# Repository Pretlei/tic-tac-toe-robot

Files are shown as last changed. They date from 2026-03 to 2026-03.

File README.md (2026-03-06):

# tic-tac-toe-robot
An autonomous Tic Tac Toe robot you can play against! Huge thanks to Maxim Beauchemin, Chris Dietcher, and Andrew Jang for their shared commitment and hard work that made this project possible.

## Project Overview:
An autonomous Tic Tac Toe Robot built using VEX IQ and Tetrix components, as well as 3D printed parts and an aluminum extrusion. Uses a 3-axis motor system with color and distance sensors to interact with the X's and O's. Programmed game logic and robot instructions using C++ and VEX IQ Code. 



Read the Final Report for in-depth documentation and code!

## Links to Demo Videos
Pick and Place Demonstration: https://drive.google.com/file/d/1chxBTSAvIlYaxoZVmUNdCmPReI9nGJBg/view?usp=sharing

Scan and Play Demonstration: https://drive.google.com/file/d/1ZsqPEp68fcEzI5YiyI5k1Ya-KQUuAkkN/view?usp=sharing

## Issues with the Tic Tac Toe Robot:
- Motor inaccuracy
- Sensor inaccuracy
- Overheating of VEX IQ motors
- Slight lack of proper building components, and therefore, structural integrity

Unfortunately, time and resources were severe constraints in this project. We made the best of what we had! It was an excellent learning experience.

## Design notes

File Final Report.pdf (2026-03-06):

# The Tic-Tac-Toe Robot

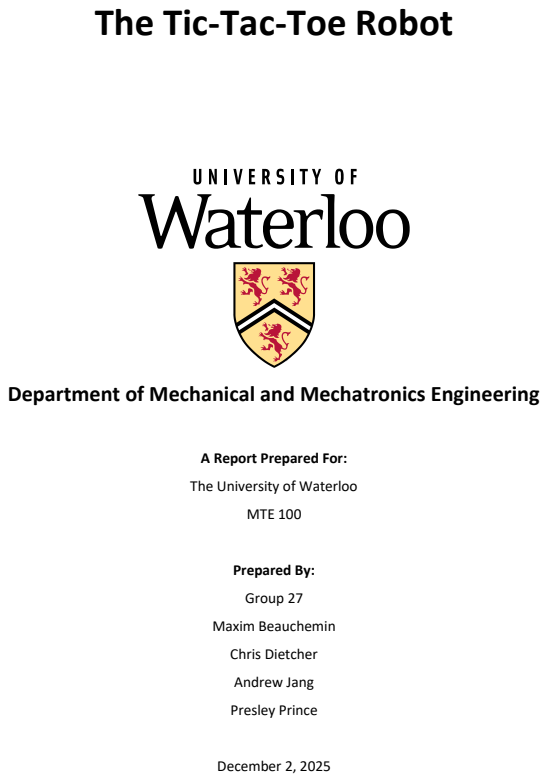
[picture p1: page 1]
MTE 100; Prepared By:; Group 27; Maxim Beauchemin; Chris Dietcher; Andrew Jang; Presley Prince; December 2, 2025

Department of Mechanical and Mechatronics Engineering

A Report Prepared For:
The University of Waterloo

i

December 2, 2025

MTE 100 and MTE 121 Teaching Teams

Department of Mechanical and Mechatronics Engineering

University of Waterloo

200 University Ave W.

Waterloo, Ontario, N2L 3G1

Dear Teaching Teams,

As a team, we would like to express our deepest gratitude to the entire teaching team. Without

you we would not have come up with this project which, while having had several very late nights and a

few clawed-out hairs, we are incredibly proud to have created.

Instruction from all our professors was essential to learn the theory to build this robot. From

Professor Bedi’s fun lectures of components and the design cycle to Abdullah’s EGAD labs, and Professor

Mostafa’s programming PowerPoints. The project design, 3D-printed parts, and C++ programming

would have all been impossible without their foundational teaching. Ryan Consell’s advice proceeding

the formal presentation was key in many parts of our design.

Additionally, the MTE 100 tutors were key in the project execution. Their continuous feedback

throughout the project and near-constant availability made many of our largest issues into just a quick

visit to their office.

Lastly, we would like to thank the amazing co-op students at WatIMake who taught us the

basics of 3D printing.

This report was written entirely by Group 27. Apart from acknowledgements listed above and

references, the program and robot were created entirely by Group 27 as well.

Best Regards,

Maxim Beauchemin

Chris Dietcher

Andrew Jang

Presley Prince

ii

## Table of Contents

iii

5.3 The Functions | 18
5.4 Data Storage | 22
5.5 Decisions and Trade-offs | 23
5.6 Testing Procedures | 24
5.7 Significant Problems | 25
6.0 Verification | 26
6.1 Fulfilled Constraints | 26
6.2 Failed Constraints | 26
7.0 Project Plan | 28
7.1 Tasks Splitting | 29
7.2 Revisions to Project Plan | 29
7.3 Project Plan vs Actual Timing | 30
8.0 Conclusions | 31
8.1 Successes | 31
8.2 Failures | 31
9.0 Recommendations | 32
9.1 Mechanical Recommendations | 32
9.2 Software Recommendations | 33
References | 34
Appendix A – C++ Code | 1

iv

## List of Figures

Figure 27. A description of the project plan after the formal presentation. Taken from the formal

v

## List of Tables

Table 1. A table of all X and Y positions for the motors for each square of the board. The position is given

in degrees and obtained from motor encoders through testing. The array indices are visualized in Figure

26 | 24

Table 2. A table of distance sensor readings corresponding to the number of pieces left in the stack. The

values assume that all pieces are left in the stack or on the board. The values were obtained through

distance sensor reading and refined in testing | 25

vi

## Summary

The MTE100 robot project for Chris, Maxim, Andrew and Presley was an autonomous tic-tac-toe

robot. This robot was designed to solve the problem of one of the team members being too busy at

university to play his cousin in tic-tac-toe.

The project started following the design cycle and discussing the constraints and criteria for robot

design. After need synthesis was complete through analysis of criteria and constraints, preliminary

designs were drafted for the robot’s function. Designs for given parts were selected and then

manufactured into a functional robot. There were many iterations of redesign adjusting both small and

large details about the robot’s design. Next, the robot was programed to play a game of tic-tac-toe,

using a color sensor to scan the board and a three-axis motor system with a claw to move pieces.

Various methods of verification were used to test the robot’s functionality and adjust

preprogramed encoder values. During the validation phase of the design cycle problems started to arise

in the robot’s functionality. Namely, the Z-axis motor was too weak to carry the load of the claw its full

vertical distance and encoders inaccuracies made piece pick up difficult for the robot. However, in the

final demo the robot was able to perform tic-tac-toe moves from various starting positions but could not

play a full game due to the previously described errors.

It is concluded, for future designs of a tic-tac-toe robot to redesign the Z-axis motor with

potentially a gearing system to reduce torque, use lead screws to increase motor encoder accuracy, and

consider using the Minimax algorithm to further optimize the robot’s gameplay.

## 1.0 Introduction

The MTE100 project is a first-year design project in which students find a problem and design a

robotics solution to solve the problem. The criteria for this project were that it must solve a problem,

use at least 3 motors and 4 inputs, and contain at least six functions in the robot’s code. This design

project report will focus on the development of an autonomous tic-tac-toe robot.

This MTE100 robot project was designed to solve the problem of one of the group members not

being able to beat his cousin at tic-tac-toe. Chris has a long-standing tic-tac-toe rivalry with his 8-year-

old cousin and cannot beat him since he is too busy studying at Waterloo. So, the group devised a plan

to make an autonomous tic-tac-toe robot to beat Chris’s cousin while he is away. The goal for this robot

was to design a simple to use, autonomous tic-tac-toe robot capable of playing full games of tic-tac-toe

with little user assistance.

Tic-tac-toe is a simple game involving players taking turns placing X’s or O’s on a 3x3 grid. The

goal is to get three X’s or O’s in a row to win. The robot is designed to be able to scan any tic-tac-toe

board and play a specific move to bring it closer to winning or tying the game. The robot is also designed

to play against a player having a button to press signifying it is the robot’s turn. This design allows it in

theory to play whole games against another player, itself or from any given valid position.

This robot was developed using Vex IQ electronics and parts, Tetrix parts and various 3d printed

elements. Vex IQ is an intuitive design framework for assembling basic robotics systems using plastic,

snap-together pieces [1]. Additionally, Vex IQ has very inaccurate sensors that were a major source of

troubleshooting for later design iterations of the robot. Tetrix parts were used for main stabilization of

robot design since the aluminum extrusions were more rigid than plastic Vex IQ parts. Lastly, custom

parts were made to fit specific functions of the robot that would be hard to model using Vex IQ or Tetrix

parts. The primary use for 3D printer was for complex parts like the Claw and Board which will be talked

about in further detail in 4.0 Mechanical Design and Implementation.

## 2.0 Scope

### 2.1 Functionality

The robot autonomously played tic-tac-toe by moving physical pieces from a stack onto a board.

The pieces and board are shown in Figure 1. To play, the robot recognized when it was its turn, scanned

the board, and placed a piece on the board.

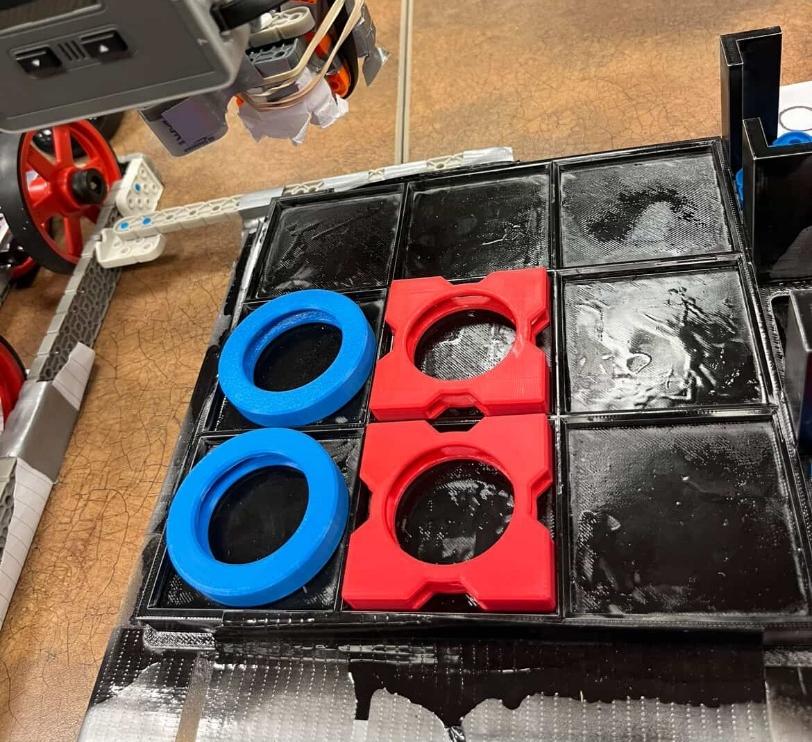
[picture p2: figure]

Figure 1. Tic-tac-toe board and pieces

During regular operation, the robot would wait for the user to make their move and press the

touchLED. The press informed the robot that it was its turn. The robot would then zero itself by moving

to its starting position. This starting position was located at the top-left corner of the board relative to

the user. In this position, the claw assembly was also raised to its highest possible elevation. The starting

position is shown in Figure 2.

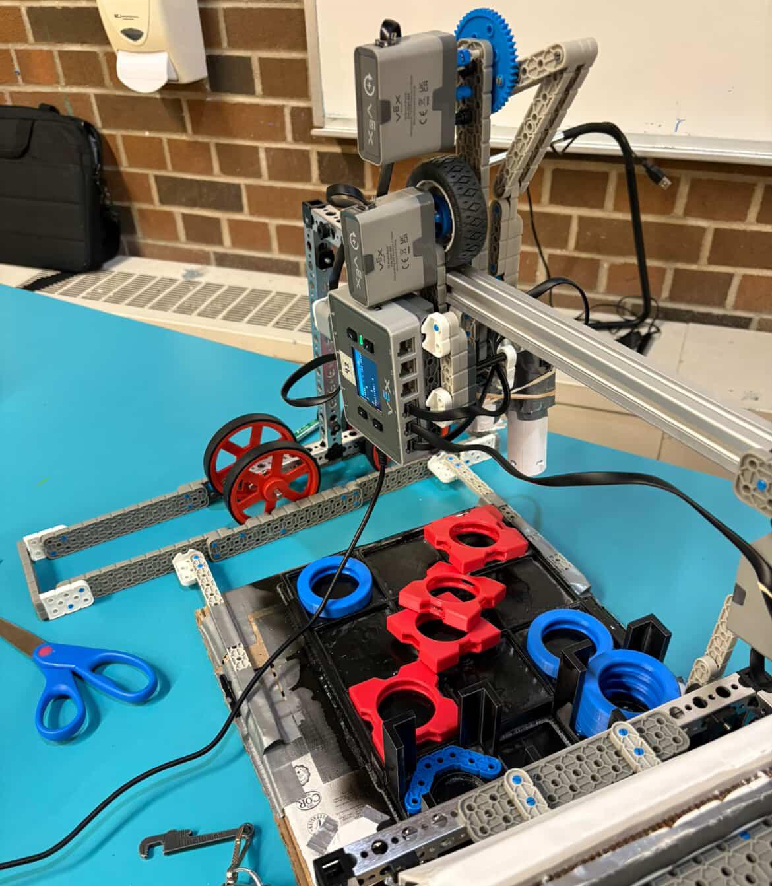
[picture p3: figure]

Figure 2. Starting position of robot

Once the robot reached its starting position, it would then proceed to scan the board. Scanning

the board allowed the robot to determine what pieces have been placed, where said pieces were, and

what piece it should place and where it should place it. Scanning the board also enabled the robot to see

if the game was over, or if any cheating has been done by the user. For this project, cheating was

defined as having an invalid number of pieces on the board. Since X always goes first, the number of X-

pieces must have been one greater or equal to the number of O-pieces on board. To scan the board, the

robot lowered the claw assembly to its scan height and then moved the color sensor (located on the

claw assembly) over each space on the board. The scan height was the lowest height the claw could go

without hitting any pieces placed on the board. This is illustrated in Figure 3. After completing the scan,

the robot returned to its starting position.

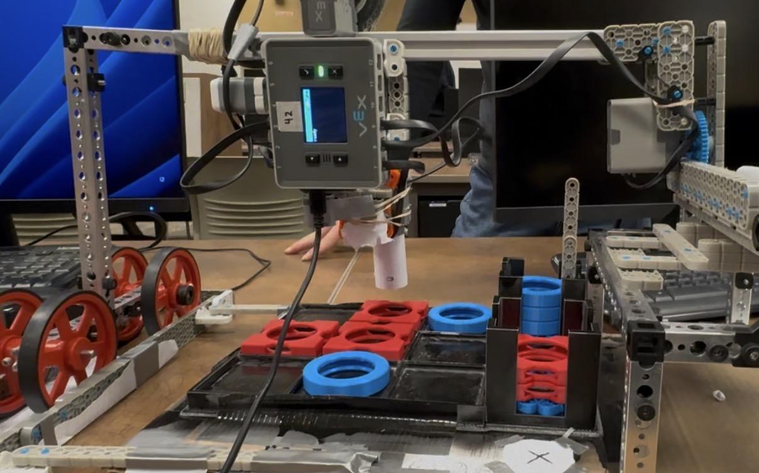
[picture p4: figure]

Figure 3. Robot scanning the board

The robot’s next task was to pick up a piece and place it on the board. This task was only

completed if the game was not over and if cheating was not detected. First, the robot would move to

the correct stack of pieces based on the scan of the board. The claw assembly would then be released

and allowed to fall to its lowest height. The claw would then be raised to the height of the top piece in

the stack. The claw was then extended into the holes of the piece. The claw assembly would then return

to its starting position for placement. After returning to the starting position, the robot moved the claw

assembly to the space it determined would result in the best move. The claw is then lowered and then

retracted, allowing the piece to fall into place on the board.

The robot then returned to the starting position and waited for the user to complete their next

turn.

### 2.2 Measurements and Readings

Throughout the robot’s operation, the robot kept track of its position, differentiating between

the different pieces on the board, and whether it was its turn. The robot also used the inputs to decide

when to end the program. The robot received readings from the touchLED, motor encoders, color

sensor, and distance sensor.

The touchLED acted as a method of communication between the user and the robot. Pressing

the touchLED informed the robot that the user had completed their turn and that it was the robot’s

turn. The touchLED also acted as the shutdown mechanism for the robot. While the robot is waiting for

the user, holding down the touchLED for three seconds or more would have shut down the robot.

The motor encoders were used to keep track of the position of the claw assembly throughout

the entire operation of the robot. This includes the position in the x-axis, y-axis, and z-axis. Keeping track

of the claw’s position was important as the robot had to move to many different locations in three-

dimensional space. These locations included each space on the board, the two stacks of pieces, and each

of the five possible heights in each stack. Only the encoder values of three of the four motors were used

to measure position; the fourth motor did not control the motion of the claw assembly. The motor

encoder values were measured in degrees.

The color sensor was used to differentiate between X-pieces, O-pieces, and empty spaces. The

X-pieces were red, the O-pieces were blue, and the board was black. When scanning space on the board,

the color sensor took 20 measurements and used the lowest hue value. See [Appendix A, line 564] for

more information on the color differentiation process.

The distance sensor was used to keep track of the height of the claw when the robot was picking

up pieces from the stacks. The distance sensor was used in place of the encoder for the z-axis motor

because the distance sensor was believed to be more accurate. Increased accuracy was required when

picking up pieces due to the small size of the pieces.

### 2.3 Interaction with the Environment

Interaction with the environment was accomplished using the robot’s four motors. Three of the

motors were used to control the position of the claw assembly. Each of these motors was responsible

for movement along one of the three main axes. One motor controlled x-axis motion; another motor

controlled y-axis motion; a third motor controlled z-axis motion. The motors and their respective axes

are shown in Figure 4. These three motors allowed the robot to reach each of the nine spaces on the

board, the two stacks, and each of the five heights in both stacks. These motors also allowed the robot

to properly position the color sensor for reading the board. The fourth motor was located on the claw

and controlled its extension and retraction. This motor enabled the robot to pick up and put down

pieces.

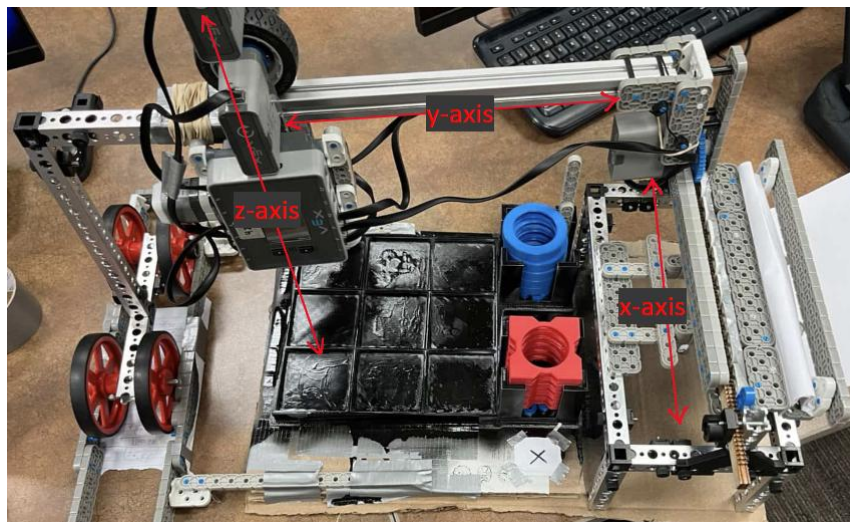
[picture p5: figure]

Figure 4. Motors and their axes

### 2.4 Task Completion

There were four main tasks the robot accomplished during regular operation: waiting for the

user, returning to the starting position, scanning the board, and placing pieces. The robot recognized the

completion of each of these tasks in different ways. Waiting for the user was completed when the

touchLED was pressed. Returning to the starting position was completed by spinning the motors in the

direction of the starting position and setting a timer. This task was completed when the timer reached

the reset time of four seconds for the x-direction and y-direction and three seconds for the z-direction.

Scanning the board was completed after the robot had hue values for all nine spaces on the board.

Placing a piece was completed after the robot moved to the location it wanted to place the piece (which

was monitored with the motor encoders) and retracted the claw.

The robot was designed to keep playing until the game was won or tied, or the robot detected

cheating. Once one of these scenarios was encountered, the robot would wait for the user to reset or

alter the board to correct the issue. As a result, the robot could play an unlimited number of Tic-Tac-Toe

games. The program only shuts down when the user holds the touchLED for three seconds between

turns.

### 2.5 Changes to Scope

Throughout the course of the project many alterations were made to the scope of the project to

improve the functionality of the robot.

One of the first changes made was the shutdown procedure. The shutdown procedure was

originally intended to be double tapping the touchLED instead of holding the touchLED. This change was made to increase the simplicity of the code. In addition, holding the touchLED felt more intuitive during

testing. Another change to the shutdown procedure was only allowing it to occur between turns. The

change was implemented for two reasons. First, it made the robot logic simpler to implement as the

robot would not be constantly checking the touchLED. Second, when the program stopped, the claw

dropped down and could hit the stacks, board, or pieces. While between turns, the robot was in the

starting position. In this position, there were no objects that the claw could hit when it fell. Only

allowing the robot to shut down between turns prevented any damage to the claw mechanism.

Another change to the functionality of the robot is the frequent zeroing of the robot. Initially,

the robot was planned to only return to its starting position at the start of its turn. While this approach

worked in principle, the inaccuracy of the motor encoders caused an accumulative positional error. The

frequent returns to the starting position made the robot more accurate and prevented any positional

errors from accumulating.

Another change to the robot was how the distance sensor was used and the piece pick up

process. Originally the distance sensor was going to be used to determine the height of the pieces in the

stack and the claw would be lowered to said height. However, this approach had two main issues. The

size of the claw made it difficult to position the distance sensor in such a way that the robot could

measure the distance to the top of the stack and grab the topmost piece. This issue is illustrated in

Figure 5. The other issue was lowering the claw to the proper height was inaccurate and resulted in the

robot grabbing the wrong piece. This is why the distance sensor was changed to measure the height of

the claw relative to the board, and the claw was dropped and then pulled back up to the desired height.

The distance sensor was given the necessary space and pulling the claw back up was more accurate than

lowering the claw.

Figure 5. Distance sensor location after redesign

## 3.0 Constraints and Criteria

### 3.1 Final Constraints and Implemented Changes

Many of the constraints concerning robot design originated from restrictions on electronic

components. The initial constraint was short wire lengths, as there was only one 400mm wire provided.

Additionally, the number of motors was limited to four, so the motion of the claw in the x and y

direction was not as reliable as it could have been. Due to these factors, the size of the board and its

pieces were limited, since three of four motors, which are connected to the brain through a wire, had to

reach all four corners of the board as shown in Figure 4. In addition, the brain’s location skewed the

movement of the aluminum extrusion in the x-direction, due to the high mass of the brain’s battery.

Furthermore, VEX IQ motors were found to be imprecise during testing, and their strength depleted

with lowering battery levels. Since the motor encoder values were battery-level specific and the rate at

which the battery depleted was high, attempts at finding the perfect measurements to reach the

different heights needed were difficult. The optical sensor was found to be imprecise as well. Red was

sometimes perceived as black and vice versa. The latter two constraints were updated to be part of the

constraints list halfway into building the robot.

Structurally, there were not enough fasteners in the kit provided to hold everything together. 4

threaded plates were bought to connect the aluminum extrusion to the wheel mechanism, but there

were many other locations at which the robot could have been more secure. Unfortunately, money was

a constraint as well, so it was not possible to buy enough fasteners to secure everything properly.

Additionally, there was an issue with 3D printer resolution, as the printed X pieces were found to be too

short compared to the specifications of the CAD model. Some pieces were also printed with rugged

textures. Finally, smooth motion with VEX IQ beams was difficult due to the ridges present in their

design. It was very easy for gears to get caught within these ridges.

### 3.2 Final Criteria and Implemented Changes

Some of the criteria that are to be discussed were derived from the constraints. These are

mentioned in this section but will be further addressed in 6.0 Verification. To account for the wire-

length constraint, it was decided that the brain would be placed onto the y-axis motion mechanism. This

was not an initial criterion; originally, the brain was supposed to be located near the linear rack system.

This was deduced from the criterion that for electronic components to work, they must be powered by

the brain using wires. Additionally, due to low motor precision, low 3D printer resolution, and claw-piece friction, there must be a reasonable amount of clearance in the fit between the claw and the

pieces, and the pieces and the board. Moreover, due to the many constraints on x-axis motion, the

mechanism responsible for it must have been reinforced.

It is required that the player be given an opportunity to play against the robot after its turn, but

it is up to the player if they wish to play. The robot must have made a turn after a press of the touchLED,

even if the player has not played. The claw must return to zero position after its move so the user can

make their move without the robot blocking them. The claw must also be able to pick up and place

pieces onto the correct square on the board. Subsequently, the claw must be able to move to all points

on the board (x-y direction) and vertically (z direction) so it can reach all possible pickup and release

positions. The claw should also be able to convert rotational motion to linear motion, since it must have

some difference in positioning, i.e. the location of the protrusions, to pick up and release pieces.

To increase reliability, it was also decided that the aluminum extrusion must be supported on

both sides due to the amount of weight that it carries, as shown in 2.2 Measurements and Readings

Figure 3.The initial design was to make it a cantilever, but that was found to be too unrealistic after

considering all possible locations of the brain and motors. The design of the claw led to the design of the

pieces, which should have circular holes so they could be picked up from the inside and be of distinct

colors for easy optical sensor and human distinction. Therefore, the optical sensor was decided as the

sensor responsible for reading information from the board. The distance sensor should have also been

used to determine the height of the stack of X and O pieces, so that the robot could determine the next

height at which a piece needs to be picked up.

### 3.3 Importance of Each Criteria and Constraint

The limited number of motors and short wire lengths were the main constraints behind the size

and positioning of the components, especially the brain, motors, and sensors of our robot. Given the

restrictions on buying external electronic components and the low accuracy of the existing ones, the

group was forced to design around these constraints. The criteria related to how tic-tac-toe is played,

such as checking for win conditions, how the robot must wait its turn, and positioning of the claw for

user convenience heavily inspired the software design of the robot. The rest of the criteria and

constraints did not guide design as much, either because they were deducted from existing constraints

or criteria, laws of nature, or because the group was aware of it since the very beginning of the project.

## 4.0 Mechanical Design and Implementation

### 4.1 Mechanical Design Overview

Throughout the course of the project, the overall and part design of the robot has been through

many iterations of the design cycle. Initially, the first drafts of the robot depicted it as a primarily crane-

like structure overtop of the board, with the main components contained inside the crane, see Figure 6.

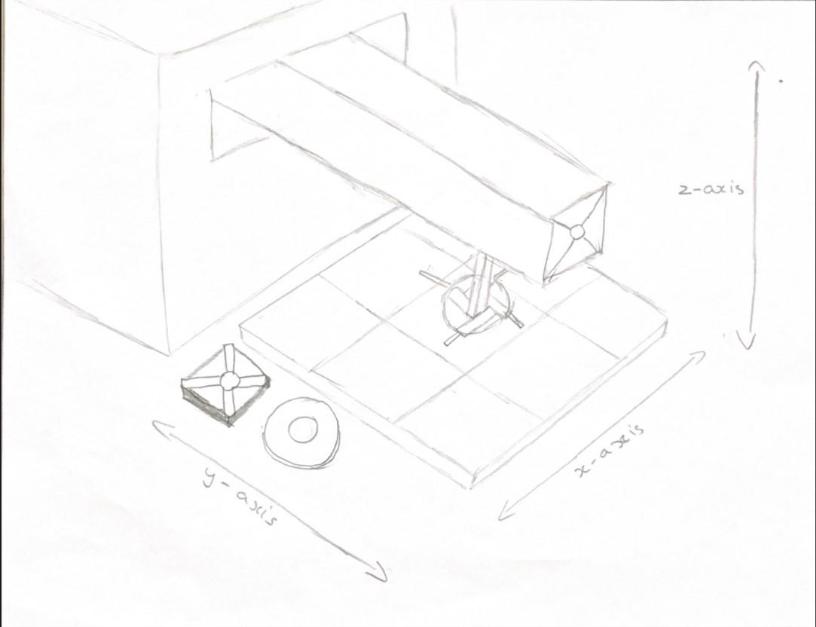
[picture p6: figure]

Figure 6. Preliminary design of Tic Tac Toe Robot

This design contained the same three axis of motion principle used in the final robot design

although it had some critical flaws. Namely, the wire length constraint prevented the storage of the

robot brain and battery inside the crane and the high torque from battery weight, as mentioned in 3.1

Final Constraints and Implemented Changes, disabled motion on the x axis. To fix these issues, the robot

design was altered to being supported on both sides with the brain mounted on the claw, as further 3.2

Final Criteria and Implemented Changes. Other edits of individual parts in the design were also made

and will be elaborated on in further sections of Mechanical Design. The final system after adding beam

support and the brain on the claw can be seen in Figure 7. This design was decided upon since it met the

criteria and functioned within the constraints described in 3.0 Constrains and Criteria. Namely, the

constraint of short cable length was the most limiting factor in the design requiring a tradeoff for a

smaller scale robot. This also hindered the tolerance for piece drop off on the board due to the board

size shrinking.

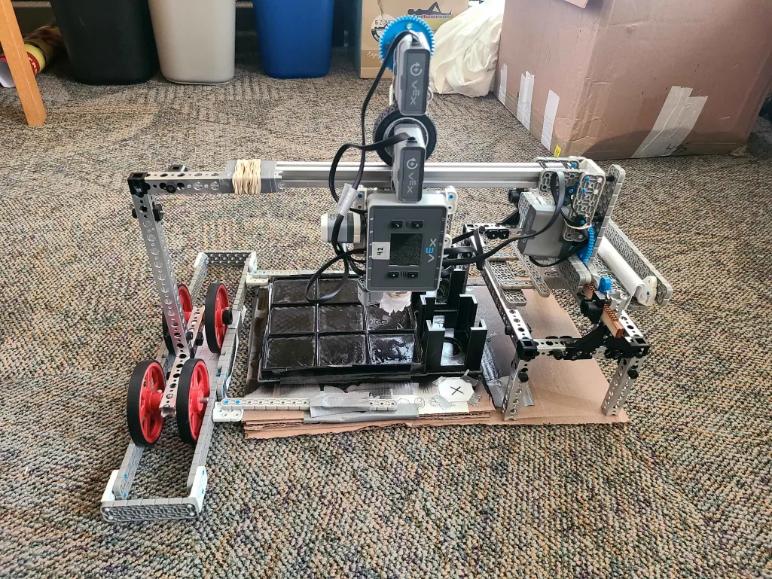
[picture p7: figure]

Figure 7. Final robot mechanical design

### 4.2 X-Axis Motor and Crane Base

The crane base is a stable structure that supports the overall robot weight during operation. It

was made using a rigid aluminum hull to guarantee structural stability and Lego to support and improve

x-axis motor functionality. Additionally, the crane base is secured to the cardboard with cut grooves to

ensure that the board is locked in a position relative to the crane, improving motor encoder accuracy.

These details can be seen above in Figure 7.

The X-axis motor originally was designed to incorporate a chain-based system for motion that

can be seen in Figure 8. Although there were a few critical flaws with this design: the wire length not

being able to reach sprocket from new brain length, mounting difficulties with Vex/Tetrix parts not

meshing well, and design difficulty as no member had previous experience with developing chain and

sprocket systems. Thus, a new design was implemented using a rack and pinion system to account for

the issues of wire length and lack of group knowledge.

Figure 8. Preliminary x-axis motion design

The rack and pinion design was then implemented. There are a few details that had to be

redesigned about this rack and pinion system before it was ready for operation. First, a firm row of

corner connectors acting as a stabilizer was put in place to ensure the pinion would not slip off. Second,

an axle support was added on the far side of the motor to decrease the load on the motor. Lastly, duct

tape was added to prevent the axle stabilizer from getting caught on the pinion guide rails. All of these

solutions are further addressed in 6.1 Fulfilling Constraints. After these mechanical redesigns, the final

X-axis motion was complete as can be seen in Figure 9.

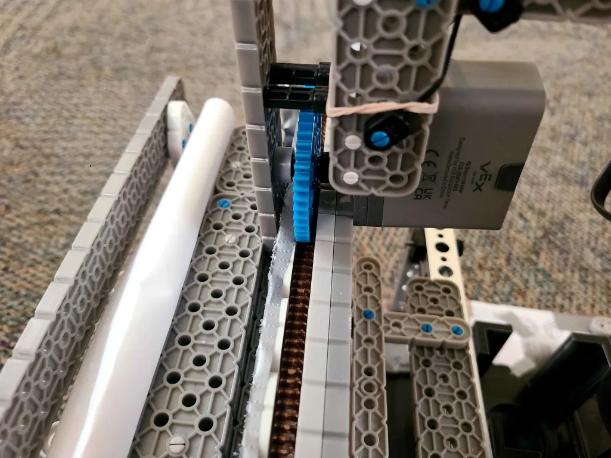
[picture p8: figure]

Figure 9. Final x-axis design

### 4.3 Y-Axis Motion and Electronics Mounting

The y-axis motion system remained mostly the same throughout the design process of the

robot. Initially in the ideation phase of development, there was some debate on whether to use a rack

and pinion system as well, or just a wheel on the aluminum extrusion. In the end it was decided to use

the wheel system for overall simplicity, outweighing the slight precision gain of a rack and pinion

system.

For the mechanical redesign of the Y-axis, the only difference between the rough drafts in

ideation phase and the final design was where the wheel was supported. In the original design the

wheel moved inside the Aluminum extrusion using the extrusion itself to hole it in place. In the final

design however, the wheel rolled on top of the extrusion, as buying an aluminum extrusion with a

groove did not meet the price range constraint. Thus, the wheel was instead supported by wrapping

around the extrusion with VEX parts. These design changes can be seen in Figure 10.

As mentioned in Section 3.2, it was decided that the brain would be mounted directly onto the

Y-axis motion mechanism. This would enable the robot to function withing the wire length constraint.

Additionally, for the reason of the brain being on the y-axis motor, the touch sensor was also mounted

on the Y-axis apparatus, to again meet wire length constraint.

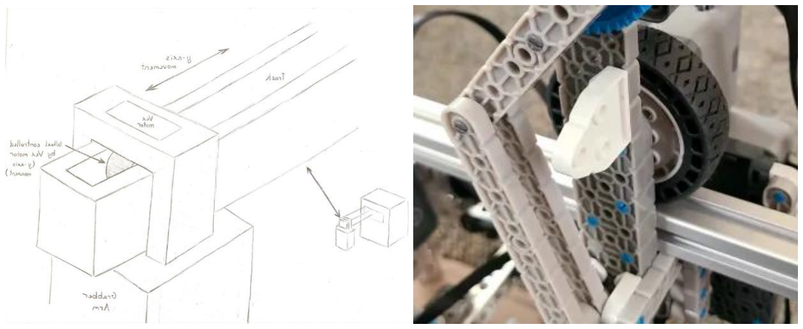
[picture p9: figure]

Figure 10. Initial vs final Y-axis design

### 4.4 The Claw

There were a few preliminary ideas that were looked at before selecting the final claw

mechanism. The main three were a clamp system, double rack and pinion and a rotary pin system, the

latter being the final design. When analyzing the different ideas, it was decided that rack and pinion was

unnecessarily complex and that a clamp system would be difficult to calibrate for lifting singular pieces

out of a stack. This resulted in the decision to use the rotary pin system seen in Figure 11. This system

works by converting the rotational motion of the axle into linear motion using guide holes in the shell of

the claw.

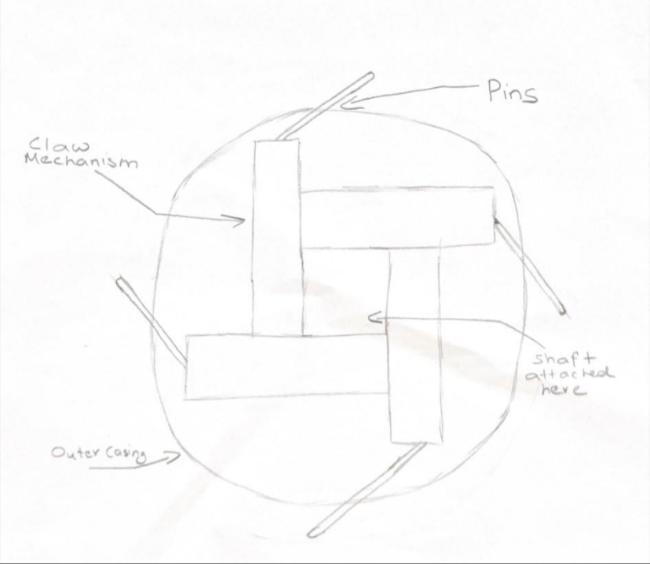
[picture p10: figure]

Figure 11. Claw design

This design remained the same in the final product as it was in the design document. However,

an aspect of the claw design that did change was the location of the sensors. Two of our criteria were

that the robot would have to be able to read the color of the pieces on the board and use the distance

sensor to determine how far down the Z-axis motor would have to go. For these criteria to be met there

were many iterations of mechanical redesign. These reiterations, and their respective solutions, are

mentioned in Section 6.1. The final design of the claw can be seen in Figure 12.

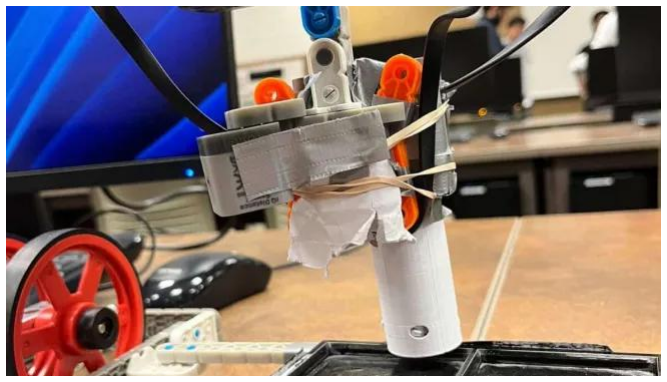
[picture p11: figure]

Figure 12. Final Claw design

### 4.5 Z-Axis Motion

The Z-axis motion was originally planned to utilize a rack and pinion system to lift the claw up

and down to required locations. However, in the final design, this was altered to a gear attached to a freely rotating rod that would convert rotational motion to linear motion with guide rails on a third rod

(see Figure 13 for more detail). The tradeoffs for this design were simplicity for precision. This new

design was much easier to manufacture as it did not require any custom parts. Although it had a major

drawback that the up and down motion was no longer linear as it would be with a rack and pinion

system. This design also caused complications in testing causing multiple iterations of redesigning due to

the ridges on the piece getting caught on guide rails. To fix this round Vex parts were used instead of

ridged squares as they had less of a tendency to get caught as the claw moved up and down.

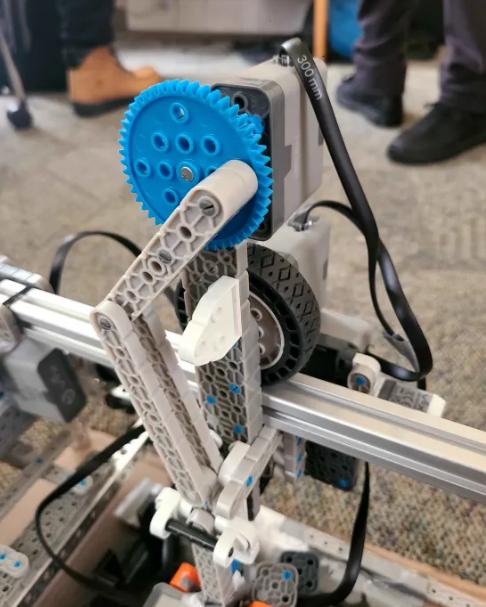
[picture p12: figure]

Figure 13. Z-axis motor

### 4.6 Support Wheel

The support wheel was added when the design was converted from a crane system to a double

support system. When implementing this design decision there was a tradeoff between high torque on x

axis motor and crane support and X-axis drift. Since the second stabilizer was made with a wheel

protruding from the far side of the robot, there was a lot of drift with the actual motion being generated

far away from the wheel. This was a large problem as it severely interfered with the preprogramed

encoder values due to variable drift on the far side. However, this design was still decided upon due to

no feasible simple solution to the torque problem in the original design could be found. Due to the

variable nature of drift in the support wheel many improvements were made throughout the

construction process. The largest one was implementing support rails for the wheels to steer their

direction making drift more predictable, as further addressed in 6.1 Fulfilled Constrains. This can be seen

in Figure 14.

Figure 14. Support wheel and its path guides.

### 4.7 Board design

The board design is a crucial part of the design that initially was planned to just be a simple 3x3

grid as seen previously in 4.1 Mechanical Design Overview Figure 6. Although as development of the

robot continued, the board design became much more essential for the function of the robot. The

primary change to the board was to add two stack holders for the X and O pieces. This change was

designed and implemented to restrict the motion of pieces in the stack enabling the claw to have more

room for error if it bumped into lower pieces. The design for these stacks also takes into consideration

that the claw pins are raised a bit from the claw shell. To account for this, a circle cut out enables the

claw to extend low enough and pick up the bottom piece. The second change was adding chamfers to all

walls on the board. This gave the robot a wider tolerance range for depositing each given piece. Lastly,

the board was painted black to reduce the reflection of light into the color senser, overall improving its

performance. Figure 15 shows the final board design after various design alterations.

Figure 15. Final board design

## 5.0 Software Design and Implementation

The written program can be found in Appendix A. This code has been slightly modified from

demonstration day to improve readability, but its functionality is unchanged.

### 5.1 Intro to the Program

The program was split into several broad categories of tasks: resetting the position, startup,

shutdown, motor movement, board reading, and the logic to determine the optimal move.

Resetting the position was an important step considering the motor controls were found to be

unreliable during testing prior to the project in MTE 121 assignments. To accommodate for the

inaccuracy, the robot zeroed itself during runtime and always did once at the beginning of the program.

The startup and shutdown procedures were incredibly important to have their own blocks because they

defined the initial position the robot was found in, defining how the robot continued by scanning the

board. The shutdown defined how the robot finished each turn.

The regular operation of the robot consisted of scanning the board, picking up, and placing the

piece in the optimal place. Motor movement, board reading, and the logic to find the optimal move

were each integral part of being able to do this. Motor movement was necessary to both move and

activate the claw. Board reading was necessary to interpret the board, and logic was to determine the

next piece’s placement.

### 5.2 Task List

Below is the task list determined for the robot demonstration.

Startup

- Program starts by hitting check mark
- Robot moves to a corner to zero all motors

Regular Operation – Expected

- Waits for touchLED to be pressed (for under 3 seconds)
- The motors move the optical sensor to each square on the board to determine whose turn it

is (X’s or O’s) and which pieces are where

- Motors move the claw to the X-stack or O-stack (depending on which turn it is)
- Motors move the claw to the correct piece height (which is determined by the distance sensor)
- Claw extends to grab the piece

- Claw is moved to the position for the optimal move
- Claw retracts to release the piece and is moved to the corner for motors to be reset

Regular Operation – Unexpected

- If the optical sensor scans the board and the game is over, or the position is invalid (such as 3 X’s

and 1 O) then it makes a noise and returns to the corner to reset position

- If the robot is not at zero at the start of the turn (it has been moved by the player) it resets its

position before moving

Shutdown Procedure

- If touchLED pressed for more than 3 seconds in between moves, robot shuts down

A few changes were made from previous task lists. One of the biggest changes was adding far

more zeroing steps, such as before and after every turn, because testing determined the robot was very

inaccurate without it. Additionally, it was originally five seconds of holding the touchLED to turn the

program off, but users were found to be impatient in testing.

### 5.3 The Functions

The most important function was main, defined at [Appendix A, line 190], because it defines

how all other function should be implemented. main was written by Maxim Beauchemin with no

parametres and return type integer as standard in C++. The flowchart below, Figure 16 demonstrates

the purpose of main, it started up the program by creating an empty array for the board, which is

further discussed in 5.4 Data Storage. It reset the position, called the waitOrEndProgram function which

determined if it is appropriate to end the program. Lastly, it did all called functions specified in Figure

16.

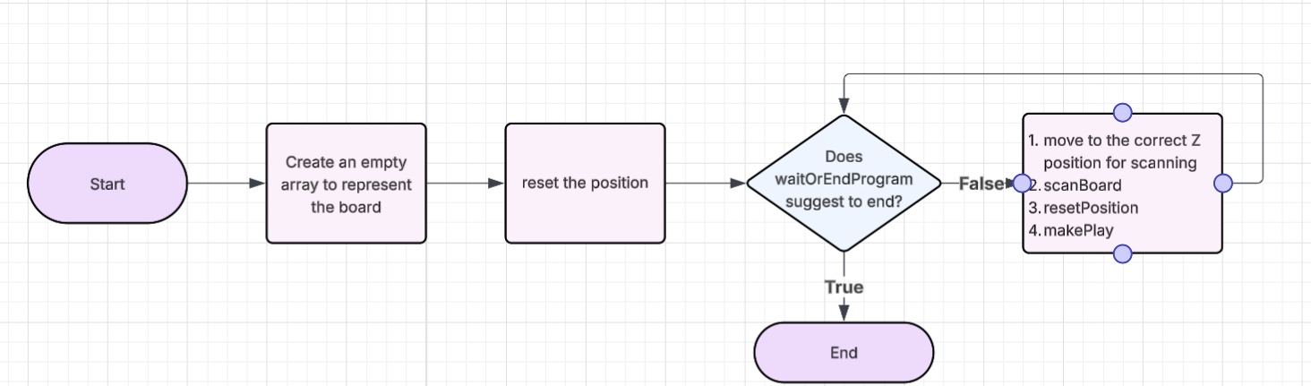
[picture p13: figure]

Figure 16. Flowchart for main

The function, configureAllSensors, defined at [Appendix A, line 220] and has no parameters and

return type void. It was written by Presley Prince and is a modified version of the function provided by

MTE 121. It is considered a trivial function, so no flow chart is provided.

The function, waitOrEndProgram, defined at [Appendix A, line 253], has no parameters and

return type bool or Boolean. It was written by Andrew Jang. As discussed above, it determined whether

the program should end by returning true if the user holds the TouchLED for a long time and false if it is

merely tapped. This functionality is displayed in Figure 17.

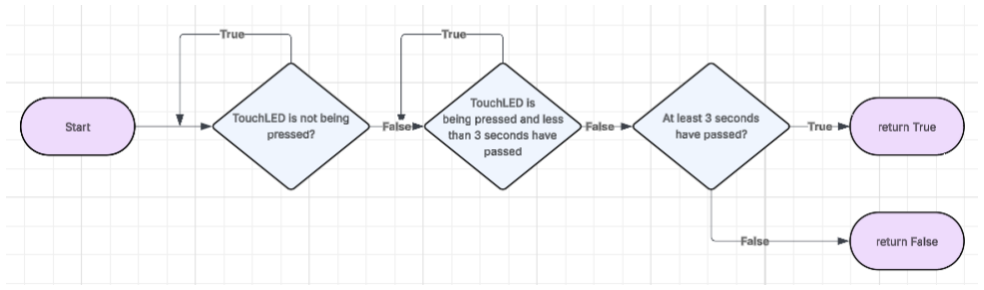
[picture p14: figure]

Figure 17. Flowchart for the waitOrEndProgram function.

The pair of function moveToXY and moveToZ, defined at [Appendix A, line 270] and defined at

[Appendix A, line 305], moved the claw to a specific x, y or z position respectively. Both were written by

Chris Dietrich and accepted appropriate parameters, integers x and y for moveToXY and integer z for

moveToZ. Neither function has a return type. The purpose of moveToXY and moveToZ are displayed in

Figure 18 and Figure 19 below. They work similarly; the robot moved in the appropriate direction until it

reached the end value given by the parameter. Their main difference, that the Z motor first releases the

brakes, is explained in 5.7 Significant Problems.

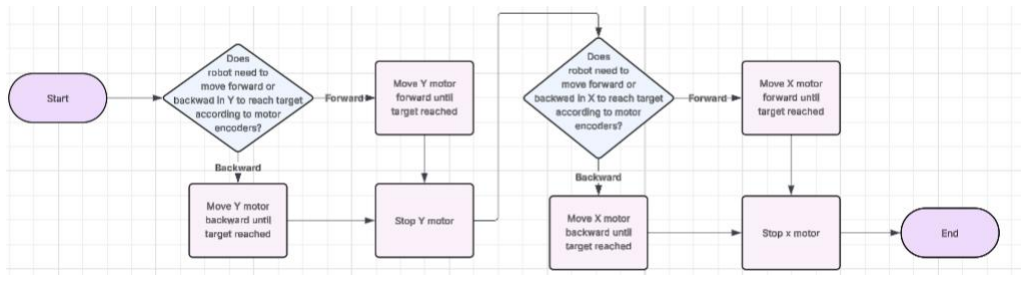
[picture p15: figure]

Figure 18. Flowchart for moveToXY.

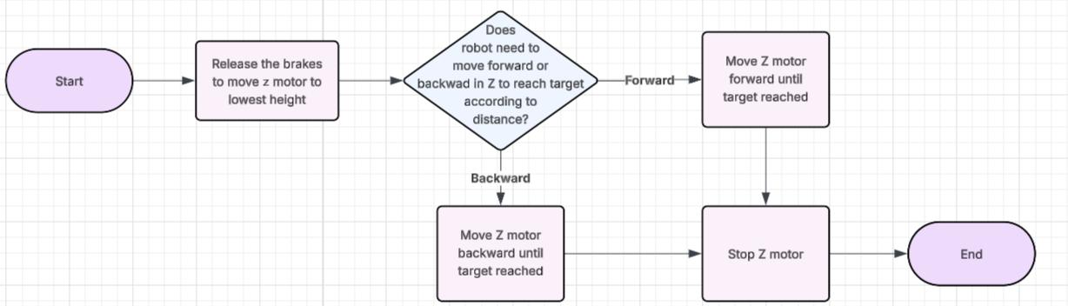
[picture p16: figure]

Figure 19. Flowchart for moveToZ

The pair of functions clawOn and clawOff, defined at [Appendix A, line 331], written by Presley

Prince control the pins on the claw, the mechanical side which was already described. Neither had any

parameters or a return type. The purpose of each function is in the name, to extend the claws, and

retract the claws, which picked up or releases an X or O piece. Figure 20 clarifies this functionality,

demonstrating that the program either checked if it has been three seconds–something would be

wrong, and this corrected it—or if it reached its target.

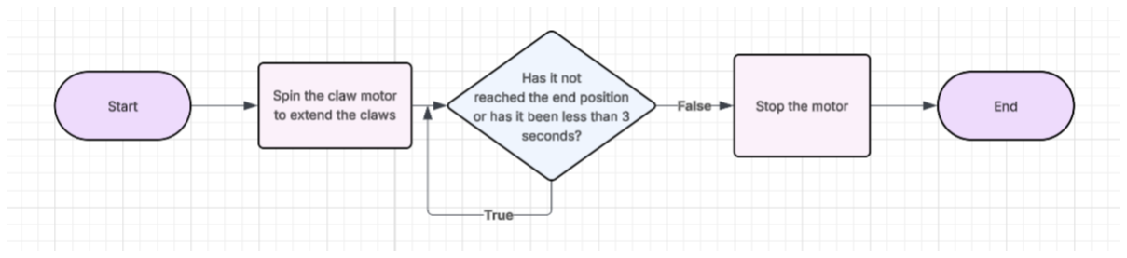
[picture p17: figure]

Figure 20. Flowchart for clawOn

The two functions subOptimalSpace and checkWin, defined at [Appendix A, line 359] and

[Appendix A, line 527], respectively, were written by Maxim Beauchemin. checkWin accepted the board

array and checked through it using a series of conditionals, as seen in Figure 21 to determine if a player

has won, returning a char variable which represents the winner. The subOptimalSquare function used

these values to predict upcoming moves. Its parameters were the current board array, a character which

represented the current turn, and an integer which represented the number of pieces left in the pile.

The latter two are reference variables so they could be updated for use in main. As Figure 22 demonstrates, subOptimalSquare created a copy of the board to modify and called checkWin to

determine if any move led to an immediate win, block the opponent from an immediate win, or led to a

win in two moves.

z

Figure 21. Flowchart for checkWin.

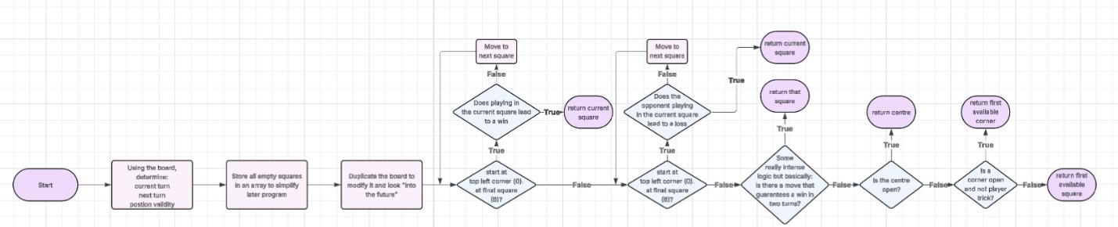
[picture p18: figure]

Figure 22. Flowchart for subOptimalSquare

The scanBoard function, defined at [Appendix A, line 564], written by Chris Dietrich, was closely

linked to both the board array because it received a pointer to that array as a parameter, and the

moveToXY function because it called it once to move to each square of the board before scanning it. As

described in the Figure 23 flowchart, it found the lowest value given by the Vex IQ Optical to decrease

error. It had no return type.

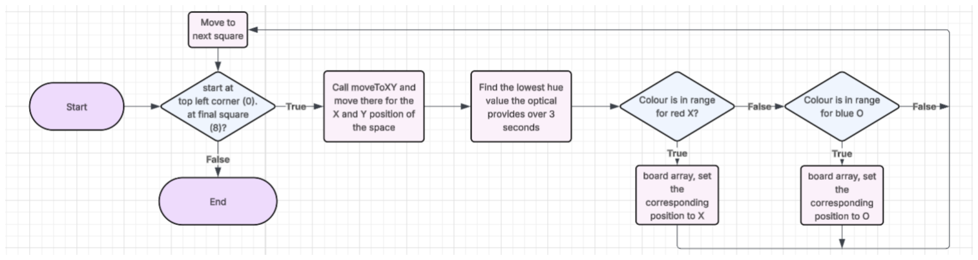
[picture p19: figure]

Figure 23. Flowchart for scanBoard

The makePlay function, defined at [Appendix A, line 601], written by Andrew Jang, was closely

related to the suboptimalPosition function because its purpose was to interpret parameters: the integer

that represents the optimal position, the current turn character and the number of remaining pieces. It

then played those moves onto the physical board using a series of function calls described in Figure 24.

It had no return type.

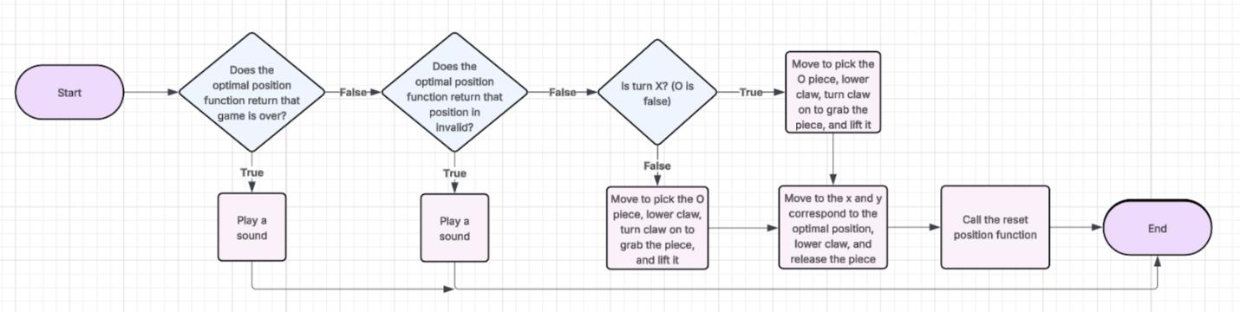
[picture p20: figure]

Figure 24. Flowchart for makePlay.

Lastly, but most importantly, the resetPosition function, defined at [Appendix A, line 652], was written

by Andrew Jang. Its purpose was to set the claw to predetermined position using a series of timers, as

illustrated in Figure 25 and set the position of the motors to zero. This ensured that the claw started in

the same position every time the program was run. It had no parameters or return type.

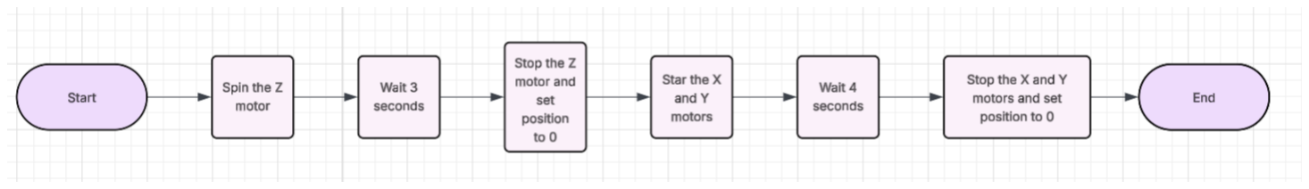
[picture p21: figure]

Figure 25. Flowchart for resetPosition.

### 5.4 Data Storage

Other than the constants, the program only had three variables, but each had an integral role in

the program. First was a character variable, turnXO, which represented the piece that the robot should

play: ‘X’ for the X piece and ‘O’ for the O piece. This was both important in the subOptimalSquare

function and the makePlay function to determine which player to find the optimal move for and where to pick up the piece. When subOptimalSquare was called, it determined the value of turnXO and

updated it through pass-by-reference.

Secondly, an integer variable, piecesLeft, represented the number of pieces left in the stack for

the current player. It was essential in determining the correct height of the piece which was to be

grabbed by the claw.

Lastly, and most importantly, was the 1D character array, board. This array stored all the

positions of the piece once scanned by the array with ‘X’ representing the X piece, ‘O’ representing the

O piece, and the space character representing an empty square. Below, Figure 26 is a graphic

representing the index associated with each position of the board.

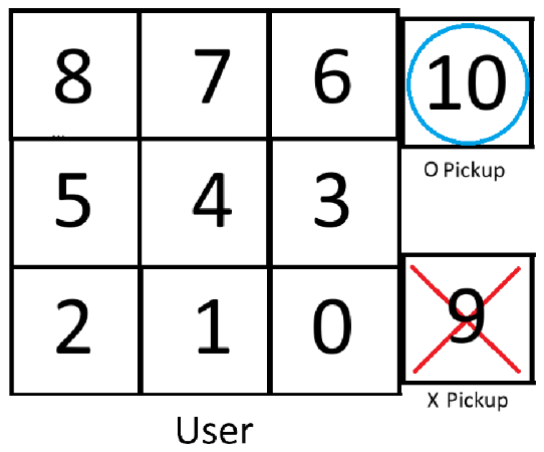
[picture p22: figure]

Figure 26. Board representation including array access indices and user location.

Throughout the entire rest of the program these values represented the three states each

square could be in which was essential for using the equality comparison.

### 5.5 Decisions and Trade-offs

Many decisions were made surrounding the robot’s program. One of the biggest was whether to

have a Tic-Tac-Toe program which always plays the best move or one that a first-year engineer could

program alone. According to , the Minmax algorithm consistently outputs the best move, however it

uses a recursive algorithm which a first-year could not independently invent. It was decided that a

different algorithm would be used: subOptimalSquare written by Maxim Beauchemin, which never lost

in testing. However, it struggled with winning because Minmax looks forward to the end of the game

while subOptimalSquare only predicts up to two moves ahead.

Another major trade-off involved the resetPosition function. When called, all motors would

head straight for a wall and attempt to continue moving past the wall. While ensuring it always reached

the reset position, it worsened the user experience through adding a long waiting time. It was decided

to maintain the functionality though because the robot could not predict its position without it.

### 5.6 Testing Procedures

To test the algorithm, a C++ program was developed using the algorithm and basic code to allow

for input and output to the console. It was tested against a variety of test cases and positions,

specifically targeting a position where it would win in one move, where the user would win in one move,

and where it could win in two moves.

To test that the board was properly scanned, the team gave it several boards to scan, especially

ensuring it could scan corner squares that it was not fully centered on. It also focused on giving it an

empty square surrounded by other pieces of the same color to test if they would be wrongfully scanned.

The major tests involved piece pickup and drop-off were involved with refining the constants

which represented different squares and heights on the board. Below, Table 1Below, Table 1, contains

the values obtained needed to drop off the board. They were additionally required for scanning. The

height of the pieces to pick up was additionally tested, and values can be seen in Table 2.

Table 1. A table of all X and Y positions for the motors for each square of the board. The position is given in degrees and

obtained from motor encoders through testing. The array indices are visualized in Figure 26.
Square | Array Index | X Position (degrees) | Y Position (degrees)
Bottom Right | 0 | -190 | 0
Bottom Middle | 1 | -190 | -100
Bottom Right | 2 | -190 | -240
Centre Left | 3 | -345 | 0
Centre Middle | 4 | -345 | -100
Centre Right | 5 | -345 | -240
Top Left | 6 | -498 | 0
Top Middle | 7 | -498 | -100
Top Right | 8 | -498 | -240
O Pickup | 9 | -470 | -362
X Pickup | 10 | -200 | -357

Table 2. A table of distance sensor readings corresponding to the number of pieces left in the stack. The values assume that all

pieces are left in the stack or on the board. The values were obtained through distance sensor reading and refined in testing.
Pieces Left | O Pickup Distance (mm) | X Pickup Distance (mm)
1 | 85 | 85
2 | 92 | 88
3 | 98 | 96
4 | 105 | 103
5 | 116 | 120

Lastly, the entire program was integrated together, and it was repeatedly tested by playing

against it using similar cases as above.

### 5.7 Significant Problems

During testing, two major problems sparked. The first problem involved the Vex IQ optical

sensor’s ability to detect the color of the pieces, which is important for determining what the next move

should be. Even one misread square leads to a completely different output, such as an extra X turning a

perfectly valid position into an invalid one. While in practice in MTE 121, the optical sensor’s light was

always turned on because it improved its ability to read colors. However, the optical sensor was much

further away from the pieces than the recommended limit, which was a major design flaw, but it had a

smart software solution. The testing process identified that when the light was off, the board’s black

color was either read as black or red, but when the light was on, all the hues suggested purple. The

solution was to take the minimum hue over two seconds, which for black, was always zero and for red,

was always roughly 300.

The second major problem was again rooted in a mechanical design flaw but was fixed with

software. The z-axis movement was very inaccurate because a small rotation caused a large

displacement and poor motors worsened the issue. The issue was more prevalent when lowering

because it was aided by gravity, but less prevalent when moving upwards because gravity would force

the motor to rotate more slowly. By switching the brakes from hold to coast, the motors would first

drop, then move upwards to the correct position, but working against gravity to decrease velocity and

achieve a more precise result. While a mechanical solution was preferred, the deadline was too soon for

a mechanical remodel.

## 6.0 Verification

### 6.1 Fulfilled Constraints

The group was logical and creative in addressing most constraints. To address the initial

constraint, short wire lengths, the brain was placed in the middle of the aluminum extrusion, where it

was most equidistant to all motors and sensors, considering the ratio of the number of small to large

wires provided. The maximum distances where the aluminum extrusion and the wheel mechanism could

move determined the length and width of the board. However, this created another constraint, the high

battery mass located at the center of the board. To account for the skew of the aluminum extrusion

when travelling in the X-direction, a guided rail was built to prevent the wheels attached to the

aluminum extrusion from straying from its path, as shown in 4.6 Support Wheel Figure 14. The limited

number of motors provided, and the amount of weight each motor had to carry, was solved by either

adding more connections or duct tape for structural integrity or by using contraptions like these to guide

motion. Another contraption can be found in the linear rack system, where a row of corner connectors

was placed on either side of the gear to prevent it from slipping.

Low 3D printer resolution was accounted for by adding more than enough clearance in the CAD

specifications of the part before 3D printing. Therefore, the claw protrusions had more than enough

space to insert themselves into the piece. Furthermore, since the group could not afford as many

fasteners as needed, duct tape was the preferred alternative to structural integrity. As for imprecision in

sensor measurements, the optical sensor was covered with paper on all sides except one to remove as

much light interference as possible. Light levels within the room during demo day and testing were also

carefully monitored. On the other hand, the distance sensor was positioned so that the surface that it

was reading was consistent, i.e., it was placed over the supporting panel of cardboard instead of the X

and O pieces as initially planned. The ridges in VEX IQ beams were resolved by tightly wrapping them

with paper. This allowed for mostly consistent smooth motion.

### 6.2 Failed Constraints

More fasteners and beams could have been added to improve the structural integrity of the

robot; however, it was in the best possible shape for the budget that the group had set. Only one real

constraint failed to be properly met in this design. Failure in resolving poor motor precision caused the

robot, specifically the motor that controls motion vertically, to be incapable of picking up pieces in a lot

of the test cases. However, poor motor precision was caused by a lot of factors, such as the weight the motor was carrying, how long it was in use, and the battery charge. It was an extremely difficult

constraint to control. Also, as mentioned before, VEX IQ’s battery power levels were depleted by nearly

5% during each test run. As motor strength is directly dependent on the battery charge, this made it

almost impossible to calculate the correct number of rotations needed to lower the claw to the right

height, given that the battery charge could be at any percentage at any time of operation.

A design update that could resolve this issue is adding gear reduction instead of directly

connecting the motor to the gear that rotates to change the height of the claw. A smaller gear could be

attached to the motor instead; the smaller gear could bite with the larger gear, allowing for less speed,

and therefore, less movement per shaft rotation, which translates to more torque, and therefore, more

control over the height of the claw. A more compact alternative to this idea is a spur gearbox that could

have offered the same benefits but at a higher cost. This change would allow for a higher acceptable

range of values for piece pick-up at each height increment of the stack, reducing its chances of failure.

## 7.0 Project Plan

The early stages were not as work intensive as the later stages, but each group member was

given one week to work independently or with another member on their tasks. This was in preparation

for our weekly meetings Monday. Since all group members all had the same class schedule, it was easy

to discover that all members had extremely open Mondays after the MTE 121 lecture and before the

MATH 115 lectures: roughly four hours. As a result, they became the designated meeting day.

The team decided to split out tasks to work in smaller groups because all four had different

schedules and varying work styles, but it allowed them to stay well on track.

The last two weeks leading up to demo day were more together, so each member was

responsible for clearing up a large section of time. The robot was kept at Village 1 since most members

lived there and it was decided as a group that meant more time for the project and less travel time.

Below, Figure 27, shows the project plan following the formal presentation.

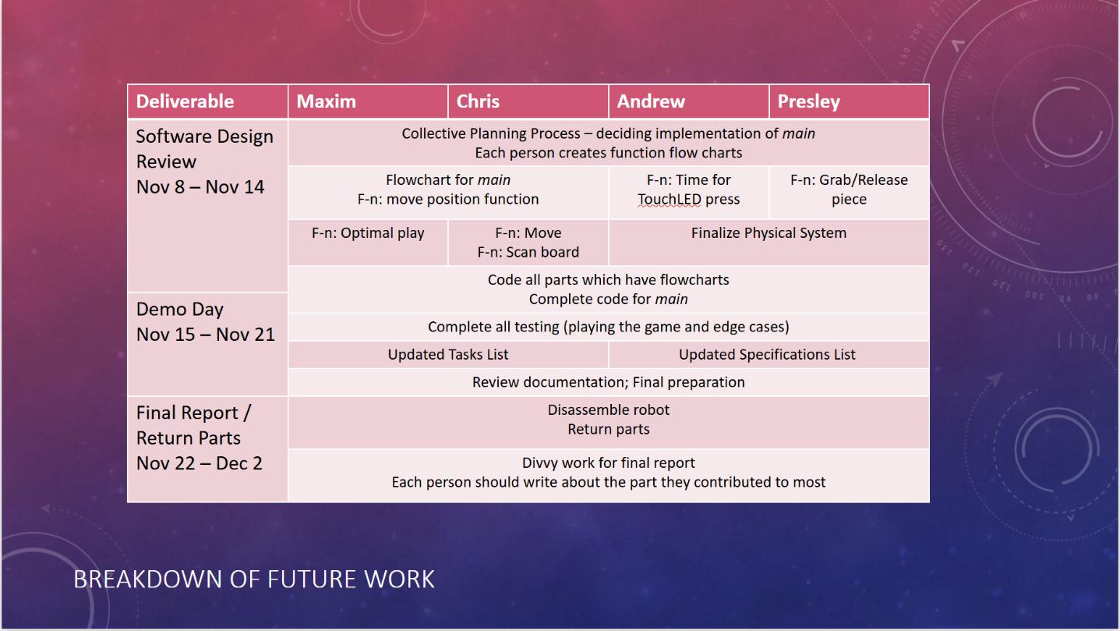
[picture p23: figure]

Figure 27. A description of the project plan after the formal presentation. Taken from the formal presentation slide show.

It also demonstrates that a significant portion of the project plan revolved around the near-

weekly deliverables. This seemingly good issue became an issue which is explained in 7.3 Project Plan vs

Actual Timing.

### 7.1 Tasks Splitting

For the mechanical half, the plan split the team into two, Maxim and Chris worked on the claw

mechanism and the board. Together, they were to create the SolidWorks models for the X and O pieces,

all parts of the claw, and the board. Maxim was additionally tasked with learning the 3D printing while

Chris was tasked with motion along the Z axis.

Andrew and Presley were to focus more on creating the frame for the robot along with motion

for the X and Y axes using a pair of racks and pinions. They were to take the dimensions Maxim gave

them for the size of pieces and the board and translated them into frame dimensions. They worked

much more on assembly than individual pieces but did additionally design the aluminum extrusion.

For the software half, each member was given roughly two functions to write. The more logically

complex functions were given to the more experienced members, Chris and Maxim, but the overall

programming time was equally split. The specifics for who was assigned each function is specified in 5.3

The Functions.

### 7.2 Revisions to Project Plan

Overall, the project plan was created and refined throughout the project to reflect on how the

team’s work progressed, so it is difficult to define strict revisions to the plan.

However, there were moments when the team was in crisis and a necessary change was made.

As seen in Figure 27, the time allocated for testing was extremely short, while simple tasks such as the

tasks and specifications lists were given equally long sections. However, as soon as testing started, the

team realized that not enough time was allocated for it, especially considering the program was not

even finished by the allocated first day of testing, which while being according to plan, was clearly a

lapse in judgement. It was agreed from then, as a revision to original plan, that every day that week,

time after lectures would be spent working on the project. It was an unfortunate sacrifice, but it was

necessary to finish by the day of the demonstration.

Another change to the project plan was to remove the flowcharts stated in Figure 27 because

they are not specified in the Software Review deliverable. While they are included in 5.3 The Functions,

they were created after the program was written. The reason for this revision was that all the group

members found creating flowcharts easier after writing the program rather than before.

### 7.3 Project Plan vs Actual Timing

For the most part, especially earlier stages of the project, the group timed everything very well

with the actual plan. The plan probably held the team back because it meant that they only had to have

a certain amount of work completed. Once they were done working, they could wait for the next

deadline.

This was especially a problem because the nine deliverables were the foundation for the timing.

For example, the first two weeks of the project were focused on assessing the need aspect of the design

cycle, but the only project idea was due, which was worth a very small part of the grade and was very

easy. At this point, the team was far ahead of schedule, but then merely waited until the next

deliverable was due.

The culmination of this issue was most apparent in the week leading up to the project

demonstration. Up to this point, the actual timing of the project was very close to the project plan.

However, the team far underestimated the amount of testing needed, as is apparent in Figure 27. The

team fell far behind, not completing the testing until very late the night before. The main issue with the

process used for generating the plan, as the team discovered that night, was that only focusing on

deliverables leads to a cram before it is due instead of consistent, much less stressful, work.

## 8.0 Conclusions

### 8.1 Successes

The robot successfully overcame many of the challenges it faced. The positioning of components

was successfully reworked to accommodate the limited wire lengths. This successful redesign ensured

that all components of the robot were operational and secure. The robot was able to move along all

three axes, although it struggled with z-axis motion as usage continued. Movement in the xy-plane was

accurate enough to successfully scan the board and place pieces. The claw mechanism worked very well

as pieces were easily caught and released by the claw. Each piece had a clearance fit with the claw and

the board that further improved the robot’s accuracy.

The robot consistently made correct decisions for piece placement when faced with a board

layout. The shutdown and starting procedures operated as expected. When faced with a completed

game or cheating, the robot successfully returned to its starting position and informed the user. From a

software perspective, the project met all criteria and constraints.

### 8.2 Failures

The robot was successful during demonstrations but required further improvements and

redesigns to improve its usability. The robot scanned the board and placed pieces in the intended

locations during testing but fell short of being able to play full Tic-Tac-Toe games. This was due to motor

control and accuracy. The primary challenge was the accuracy and power of the z-axis motor which

worsened after extended usage. The motor worked as intended if it was given a two-to-three-hour rest

period. However, after roughly half an hour to an hour of usage, the motor became noticeably weaker

and could not complete its intended tasks. The motor became unable to lift the claw up and down and

required cooldown time before its next use. Aside from this flaw in the physical design, the robot was

able to complete the tasks of scanning the board and placing pieces. If the z-axis motion were to be

reworked, the robot would have been functionally able to play Tic-Tac-Toe. However, beyond

movement in the z-axis, many additional changes would have improved the usability of the robot. These

changes are discussed in detail in 9.0 Recommendations.

## 9.0 Recommendations

### 9.1 Mechanical Recommendations

As mentioned in 6.2 Failed Constraints, a change to address the imprecision of the motor

controlling the height of the claw is to add gear reduction to it, which can either be accomplished by

meshing a smaller gear that is connected to the motor to a larger gear, or by adding a spur gearbox for a

more compact solution. Less speed and higher torque allow for more control over the height of the

claw, since it increases the range of values acceptable for each height at which a piece may lie. This

would make it easier to determine the correct motor encoder values during testing.

Another way to improve the robot would be to redesign the board. Each space on the board

should be deepened and the angle of the chamfers on the board should be steeper. The increased depth

of the squares on the board would decrease how much each piece sticks out above the board. This

would have made scanning the board easier. A problem with the original board was that the color

sensor would read the color from surrounding pieces. With taller walls between pieces, the surrounding

pieces would not be an issue. The steeper chamfers would ensure that the pieces slide into the proper

position after being released by the claw. During testing, the robot would sometimes place pieces off-

centered enough to stick out above the board Figure 28. This created some problems when scanning the

board as claw hangs very close to the board.

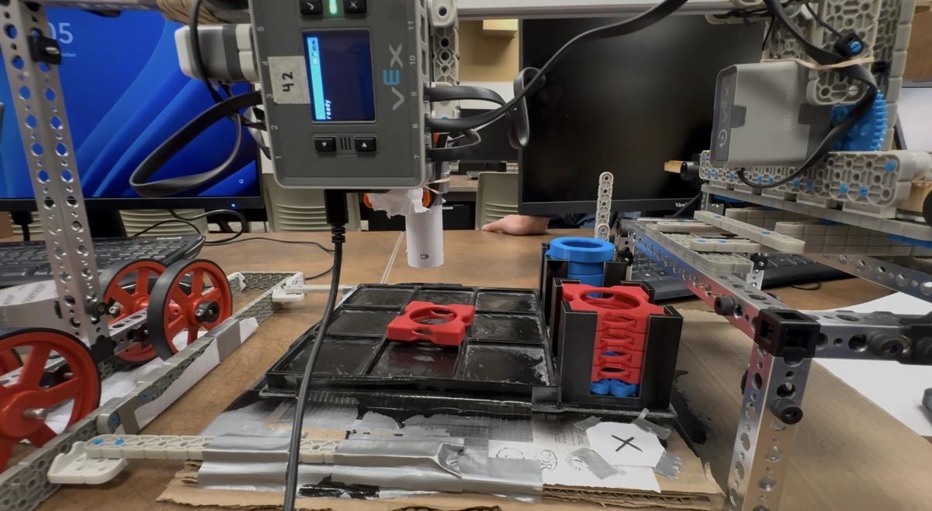
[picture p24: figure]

Figure 28. Piece was placed off-centered by robot

Lead screws should also be used to control motion along the three axes. Using lead screws

would convert the rotational motion provided by the VEX motors into linear motion as required. Lead

screws would have been a more viable alternative to the rack and pinon, wheels, and gears used on the

robot. The main benefits of using lead screws are their ability to handle high axial loads and move with

greater precision [3]. The increased precision and strength would allow the robot to consistently reach

desired heights thereby increasing the functionality of the robot. This redesign would also be less

demanding for the z-axis motor. The robot design in this project placed plenty of force on the z-axis

motor. The motor would have to constantly work to keep the claw in the raised position. Using a lead

screw would allow for the transfer of weight of the claw off the motor.

### 9.2 Software Recommendations

There are two main flaws with the software that would ideally be changed, but due to the time

constraints of the project and limitations of team composition consisting of solely first year students.

Firstly, the algorithm for determining the optimal move, subOptimalMove, relies on a series of

only scans two moves into the future. There is potential that the robot could be beaten. However, if the

program used a recursive algorithm, like the Minmax algorithm in , it could scan to the end of the game

because it would give any potential boards back to itself to keep looking for potential boards.

Secondly, a major improvement to the software surrounds the constants used. If the project had

more time, or if the plan was better from the start, more testing time would be available. With this

testing time, the team could refine the constants, especially concerning the pick-up, z heights for the

pieces, which were often inaccurate even with all improvements. It would be impossible to perfect

because the main issue was mechanical 9.1 Mechanical Recommendations, but they could be refined for

the initial condition of the motor before it heats up.

## References

[1] Vex Robotics, "IQ," Vex Robotics, [Online]. Available: https://www.vexrobotics.com/iq. [Accessed 1

December 2025].

[2] J. Fox, "Tic Tac Toe: Understanding the Minimax Algorithm," never stop building, 13 December

2013. [Online]. Available: https://blogs.cornell.edu/info2040/2022/09/13/56590/. [Accessed 29

November 2025].

[3] G. Leo, “Lead Screws: Mechanics, Design, and Applications,” Madearia, 19 August 2025. [Online].

Available: https://www.madearia.com/blog/lead-screws-mechanics-design-and-applications/.

[Accessed 1 December 2025].

A1

## Appendix A – C++ Code

#pragma region VEXcode Generated Robot Configuration

// Make sure all required headers are included.

#include <stdio.h>

#include <stdlib.h>

#include <stdbool.h>

#include <math.h>

#include <string.h>

#include "vex.h"

using namespace vex;

// Brain should be defined by default

brain Brain;

// START IQ MACROS

#define waitUntil(condition)

do {

wait(5, msec);

} while (!(condition))

#define repeat(iterations)

for (int iterator = 0; iterator < iterations; iterator++)

// END IQ MACROS

// Robot configuration code.

inertial BrainInertial = inertial();

motor MotorX = motor(PORT8, true);

motor MotorY = motor(PORT6, true);

motor MotorZ = motor(PORT2, false);

motor MotorClaw = motor(PORT9, true);

optical Optical1 = optical(PORT1);

touchled TouchLED3 = touchled(PORT3);

distance Distance7 = distance(PORT7);

A2

// generating and setting random seed

void initializeRandomSeed(){

wait(100,msec);

double xAxis = BrainInertial.acceleration(xaxis) * 1000;

double yAxis = BrainInertial.acceleration(yaxis) * 1000;

double zAxis = BrainInertial.acceleration(zaxis) * 1000;

// Combine these values into a single integer

int seed = int(

xAxis + yAxis + zAxis
);

// Set the seed

srand(seed);
}

// Converts a color to a string

const char* convertColorToString(color col) {

if (col == colorType::red) return "red";

else if (col == colorType::green) return "green";

else if (col == colorType::blue) return "blue";

else if (col == colorType::white) return "white";

else if (col == colorType::yellow) return "yellow";

else if (col == colorType::orange) return "orange";

else if (col == colorType::purple) return "purple";

else if (col == colorType::cyan) return "cyan";

else if (col == colorType::black) return "black";

else if (col == colorType::transparent) return "transparent";

else if (col == colorType::red_violet) return "red_violet";

else if (col == colorType::violet) return "violet";

else if (col == colorType::blue_violet) return "blue_violet";

else if (col == colorType::blue_green) return "blue_green";

else if (col == colorType::yellow_green) return "yellow_green";

else if (col == colorType::yellow_orange) return "yellow_orange";

else if (col == colorType::red_orange) return "red_orange";

else if (col == colorType::none) return "none";

A3

else return "unknown";
}

// Convert colorType to string

const char* convertColorToString(colorType col) {

if (col == colorType::red) return "red";

else if (col == colorType::green) return "green";

else if (col == colorType::blue) return "blue";

else if (col == colorType::white) return "white";

else if (col == colorType::yellow) return "yellow";

else if (col == colorType::orange) return "orange";

else if (col == colorType::purple) return "purple";

else if (col == colorType::cyan) return "cyan";

else if (col == colorType::black) return "black";

else if (col == colorType::transparent) return "transparent";

else if (col == colorType::red_violet) return "red_violet";

else if (col == colorType::violet) return "violet";

else if (col == colorType::blue_violet) return "blue_violet";

else if (col == colorType::blue_green) return "blue_green";

else if (col == colorType::yellow_green) return "yellow_green";

else if (col == colorType::yellow_orange) return "yellow_orange";

else if (col == colorType::red_orange) return "red_orange";

else if (col == colorType::none) return "none";

else return "unknown";
}

void vexcodeInit() {

// Initializing random seed.

initializeRandomSeed();
}

#pragma endregion VEXcode Generated Robot Configuration

//----------------------------------------------------------------------------

A4

105 | //
106 | // Module: | main.cpp
107 | // Author: | {author}
108 | // Created: | {date}
109 | // Description: IQ project
110 | //
111 | //----------------------------------------------------------------------------
112
113 | // Include the IQ Library
114 | #include "iq_cpp.h"
115
116 | // Allows for easier use of the VEX Library
117 | using namespace vex;
118
119 | // Global constants
120 | const int NUM_OF_COLOURS = 2;
121 | const int NUM_SQUARES = 9;
122 | const int DIMENSIONS = 2;
123 | const int GAME_OVER = -1;
124 | const int INVALID_POSITION = -2;
125 | const double ACTION_WAIT_TIME = 1;
126
127 | // array access constants
128 | const int BOT_R = 0;
129 | const int BOT_C = 1;
130 | const int BOT_L = 2;
131 | const int MID_R = 3;
132 | const int MID_C = 4;
133 | const int MID_L = 5;
134 | const int TOP_R = 6;
135 | const int TOP_C = 7;
136 | const int TOP_L = 8;
137 | const int X = 0;
138 | const int Y = 1;
139

A5

// array of physical board positions in degrees from reset position

// will all be negative because it is motion in reverse

const int BOARD_POSITIONS[NUM_SQUARES + NUM_OF_COLOURS][DIMENSIONS] = {

{-190, 0},

{-190, -100},

{-190, -240},

{-345, 0},

{-345, -100},

{-345, -240},

{-498, 0},

{-498, -100},

{-498, -240},

{-470, -362}, // X pickup

{-200, -357}, // O pickup
};

// function prototypes

// configures all sensors we will use. a modified variation of the given function

void configureAllSensors();

// waits for the TouchLED to be pressed and released and returns 1 if time of

// pressing exceeds 5 seconds

bool waitOrEndProgram();

// move the claw to a specified x, y, and z

void moveToXY(int x, int y);

void moveToZ(int z);

// switches the claw from grabbing to not grabbing a piece or vice versa

void clawOn();

void clawOff();

// returns the optimal position for play given a board

int subOptimalSquare(const char board[], char& turnXO, int& piecesLeft);

A6

// helper function for optimalSpace

char checkWin(const char board[]);

// scan the board to change the board array to correspond to the physical board

// calls the moveTo function

void scanBoard(char board[]);

// receives the optimal position, picks up a piece, moves to the position, and places

// it down

void makePlay(int optPosition, char turnXO, int piecesLeft);

// resets the position and zereos the motor encoders

void resetPosition();

// main

int main() {

// Initializing Robot Configuration. DO NOT REMOVE!

vexcodeInit();

configureAllSensors();

const int NUM_SQUARES = 9;

const int SCAN_Z = 75;

// represents the board as an array

char board[NUM_SQUARES] = {' ', ' ', ' ', ' ', ' ', ' ', ' ', ' ', ' '};

char currTurn = ' '; // represents who's turn it is

int piecesLeft = 0; // pieces left in the stack for whoever's turn it is

// startup procedure

resetPosition();

Brain.Screen.print("ready");

Brain.Screen.newLine();

// the program should repeat until the waitForTouch returns 1

while (!waitOrEndProgram())

A7

210 | {
211 | moveToZ(SCAN_Z);
212 | scanBoard(board);
213 | resetPosition();
214 | makePlay(subOptimalSquare(board, currTurn, piecesLeft), currTurn, piecesLeft);
215 | }
216 | Brain.programStop();
217 | return 0;
218 | }
219
220 | void configureAllSensors()
221 | {
222 | const int MOTOR_POWER_X = 25;
223 | const int MOTOR_POWER_Y = 15;
224 | const int MOTOR_POWER_Z = 60;
225 | const int MOTOR_POWER_CLAW = 15;
226
227 | // calibrate the inertial
228 | BrainInertial.setHeading(0,degrees);
229 | BrainInertial.setRotation(0,degrees);
230 | BrainInertial.calibrate();
231 | wait(2, seconds);
232
233 | // set up motors
234 | MotorX.setPosition(0, degrees);
235 | MotorY.setPosition(0, degrees);
236 | MotorZ.setPosition(0, degrees);
237 | MotorClaw.setPosition(0, degrees);
238 | MotorX.setVelocity(MOTOR_POWER_X, percent);
239 | MotorY.setVelocity(MOTOR_POWER_Y, percent);
240 | MotorZ.setVelocity(MOTOR_POWER_Z, percent);
241 | MotorClaw.setVelocity(MOTOR_POWER_CLAW, percent);
242 | MotorX.setStopping(hold);
243 | MotorY.setStopping(hold);
244 | MotorZ.setStopping(hold);

A8

MotorClaw.setStopping(brake);

// screen and optical

Optical1.setLight(ledState::off);

Brain.Screen.clearScreen();

Brain.Screen.setFont(mono15); }

bool waitOrEndProgram()
{

const int PROGRAM_END_TIME = 3;

// waits for TouchLED to be pressed

while(!TouchLED3.pressing())
{}

// if TouchLED is pressed for longer than 3 seconds, the program ends

Brain.Timer.reset();

while(TouchLED3.pressing() && Brain.Timer.value() < PROGRAM_END_TIME) {}

if(Brain.Timer.value() >= PROGRAM_END_TIME)

return true;

return false;
}

void moveToXY(int x, int y)
{

// moves backward in Y until reaching a position

if (MotorY.position(degrees) > y)
{

MotorY.spin(reverse);

while(MotorY.position(degrees) > y) {}
}

A9

// moves forward in Y until reaching a position

else if (MotorY.position(degrees) < y)
{

MotorY.spin(forward);

while(MotorY.position(degrees) < y) {}
}

MotorY.stop();

// same for X as for Y

if (MotorX.position(degrees) > x) {

MotorX.spin(reverse);

while(MotorX.position(degrees) > x) {}
}

else if (MotorX.position(degrees) < x) {

MotorX.spin(forward);

while(MotorX.position(degrees) < x) {}
}

MotorX.stop();
}

void moveToZ(int z)
{

// dropping the motor, then lifting it, helps because it is more accurate going up

// then down

MotorZ.setStopping(coast);

MotorZ.stop();

MotorZ.setStopping(hold);

wait(ACTION_WAIT_TIME, seconds);

// uses the distance sensor to determine the height of the robot

A10

if (Distance7.objectDistance(mm) < z) {

MotorZ.spin(reverse);

while(Distance7.objectDistance(mm) < z) {}
}

// would only move down slightly if it has not dropped to the bottom

else if (Distance7.objectDistance(mm) > z)
{

MotorZ.spin(forward);

while(Distance7.objectDistance(mm) > z) {}
}

MotorZ.stop();
}

void clawOn()
{

const int CLAW_DEGREES_EXTENDED = 70;

const int STOP_TIME = 3;

// spins the claw until it is extended or it has spun for too long

Brain.Timer.reset();

MotorClaw.spin(forward);

while(MotorClaw.position(degrees) <= CLAW_DEGREES_EXTENDED

&& Brain.Timer.value() < STOP_TIME)
{}

MotorClaw.stop();
}

void clawOff()
{

const int STOP_TIME = 1;

const int CLAW_DEGREES_RETRACTED = 1;

A11

// spins the claw until it is retracted or it has spun for too long

Brain.Timer.reset();

MotorClaw.spin(reverse);

while(MotorClaw.position(degrees) >= CLAW_DEGREES_RETRACTED

|| Brain.Timer.value() < STOP_TIME)
{}

MotorClaw.stop();
}

int subOptimalSquare(const char board[], char& currTurn, int& piecesLeft) {

const int X_PIECES = 5;

const int O_PIECES = 4;

int numX = 0, numO = 0;

char nextTurn = ' ';

char futureBoard[NUM_SQUARES] = {' '};

// counts how many of each colour have been played

for(int i = 0; i < NUM_SQUARES; i++)
{

if (board[i] == 'X')

numX++;

else if (board[i] == 'O')

numO++;
}

// finds the current turn and number of pieces left for the person in that turn

if (numX == numO + 1)
{

currTurn = 'O';

piecesLeft = O_PIECES - numO; }

else if (numO == numX)
{

currTurn = 'X';

A12

piecesLeft = X_PIECES - numX;
}

else // checks that the position is valid

return INVALID_POSITION;

// checks if the game is over

if(checkWin(board) != ' ')

return GAME_OVER;

// finds the next turn

if(currTurn == 'X')

nextTurn = 'O';

else

nextTurn = 'X';

// creates the modifiable board

for (int i = 0; i < NUM_SQUARES; i++)

futureBoard[i] = board[i];

// creates an array with all empty squares

int emptySquares[NUM_SQUARES] = {0};

int numEmptySquares = 0;

// finds all empty squares

for (int i = 0; i < NUM_SQUARES; i++)

if (board[i] == ' ')
{

emptySquares[numEmptySquares] = i;

numEmptySquares++;
}

// checks if immediate win

for (int i = 0; i < numEmptySquares; i++) {

// updates the potential future board

A13

futureBoard[emptySquares[i]] = currTurn;

// plays in a square if it is empty and results in an immediate win

if (checkWin(futureBoard) == currTurn)

return emptySquares[i];

// resets the modifiable board

futureBoard[emptySquares[i]] = board[emptySquares[i]]; }

// checks if another piece could be played by the opposite player

if (numEmptySquares > 1)

// checks if immediate loss

for (int i = 0; i < numEmptySquares; i++) {

// updates the potential future board

futureBoard[emptySquares[i]] = nextTurn;

// plays in a square if it is empty and results in an immediate loss

if (checkWin(futureBoard) == nextTurn)

return emptySquares[i];

// resets the modifiable board

futureBoard[emptySquares[i]] = board[emptySquares[i]]; }

// very complicated ALERT! proceed with caution (:

// checks for a guaranteed win in 2 turns

// must be at least 2 pieces left of robot's type to win in 2 turns

if (numEmptySquares > 2)
{

// runs through all possibilities of robot plays

for (int i = 0; i < numEmptySquares; i++)
{

A14

// variable to count the number of ways to win based on what opponent plays

int numWin = 0;

futureBoard[emptySquares[i]] = currTurn; // possible move is made

// runs through all possibilities of human play based on robot play

for (int j = 0; j < numEmptySquares; j++)
{

if (i != j) // checks that it does not play in the same spot as played before {

futureBoard[emptySquares[j]] = nextTurn; // possible move is made

// tests if based on a possible move in two turns if the robot could

//guarantee a win

bool foundWin = 0;

for (int k = 0; k < numEmptySquares && !foundWin; k++)
{

// checks that it does not play in the same spot as played before

if (i != k && j != k)
{

futureBoard[emptySquares[k]] = currTurn; // possible move is made

// checks if based on a possible move the robot makes, that one of the

// moves that the opponent makes

// leads to an immediate win

if (checkWin(futureBoard) == currTurn) {

numWin++;

foundWin = 1;
}

// resets the board

futureBoard[emptySquares[k]] = board[emptySquares[k]]; }
}

A15

futureBoard[emptySquares[j]] = board[emptySquares[j]]; // resets the board }
}

futureBoard[emptySquares[i]] = board[emptySquares[i]]; // resets the board

// checks that for a possible move the robot makes,

// all possible moves the opponent makes lead to an immediate win

if(numWin == numEmptySquares - 1)

return emptySquares[i];
}
}

// plays in this order if it sees no danger or immediate threat:

// centre, corner, side

if (board[MID_C] == ' ')

return MID_C;

// a common trick is used by players. conditional checks to prevent the robot

// losing to the trick

if (!(board[BOT_C] == ' ' && board[TOP_C] == ' ' && board[MID_L] == ' '

&& board[MID_R] == ' ' && board[MID_C] == 'O'

&& ((board[TOP_L] == 'X' && board[BOT_R] == 'X') || (board[TOP_L] == 'X'

&& board[BOT_R] == 'X'))))
{

for (int i = 0; i < numEmptySquares; i++)

if (emptySquares[i] % 2 == 0) // all corners are even

return emptySquares[i];
}

// if nothing else, just play in the first empty square

for (int i = 0; i < numEmptySquares; i++)

return emptySquares[i];

// code should never reach here, but just in case

return INVALID_POSITION;

A16

}

char checkWin(const char board[]) {

const int NUM_SIDE_SQUARES = 3;

// Checking two diagonals for wins

if (board[MID_C] == board[BOT_R] && board[TOP_L] == board[BOT_R]

&& board[BOT_R] != ' ')

return board[BOT_R];

if (board[MID_C] == board[BOT_L] && board[TOP_R] == board[BOT_L]

&& board[BOT_L] != ' ')

return board[BOT_L];

// Checking rows

for (int i = BOT_R; i <= TOP_L; i += NUM_SIDE_SQUARES)

if (board[i+MID_C-MID_R] == board[i] && board[i+MID_L-MID_R] == board[i]

&& board[i] != ' ')

return board[i];

// Checking columns

for (int i = BOT_R; i <= BOT_L; i++)

if (board[i+NUM_SIDE_SQUARES] == board[i] &&

board[i+NUM_SIDE_SQUARES+NUM_SIDE_SQUARES] == board[i] && board[i] != ' ')

return board[i];

// Checking for tie

bool tie = 1;

for (int i = BOT_R; i <= TOP_L; i++)

if (board[i] == ' ')

tie = 0;

if (tie)

return 'T';

// If nothing, then the game is still going

A17

else

return ' ';
}

void scanBoard(char board[])
{

const int X_PIECE_HUE_MAX = 358;

const int X_PIECE_HUE_MIN = 339;

const int O_PIECE_HUE_MAX = 295;

const int O_PIECE_HUE_MIN = 200;

const int NUM_HUE_CHECKS = 20;

const int OPTICAL_X_OFFSET = 100;

const double SCAN_WAIT_TIME = 0.1;

// loops through each position of the board

for (int i = 0; i < NUM_SQUARES; i++)
{

// moves to a sqsuare

moveToXY(BOARD_POSITIONS[i][X] + OPTICAL_X_OFFSET, BOARD_POSITIONS[i][Y]);

// scans the colour 20 times. The optical is inconsistent, but the lowest value

// it finds

// is more consistent, so that is what is used

int pieceHue = Optical1.hue();

for (int i = 0; i < NUM_HUE_CHECKS; i++)
{

if (Optical1.hue() < pieceHue)

pieceHue = Optical1.hue();

wait(SCAN_WAIT_TIME, seconds); }

// checks what the hue represents as a board piece

if (pieceHue < X_PIECE_HUE_MAX && pieceHue > X_PIECE_HUE_MIN)

board[i] = 'X';

else if(pieceHue < O_PIECE_HUE_MAX && pieceHue > O_PIECE_HUE_MIN)

A18

board[i] = 'O';

else

board[i] = ' ';
}
}

void makePlay(int optPosition, char turnXO, int piecesLeft) {

// array access constants for pickup positions

const int X_PICKUP = 9;

const int O_PICKUP = 10;

const int MAX_NUM_PIECES = 5;

// distance sensor heights in mm based on

const int PICKUP_X_Z[MAX_NUM_PIECES] = {85, 88, 96, 103, 120};

const int PICKUP_O_Z[MAX_NUM_PIECES] = {85, 92, 78, 105, 116};

// if the position is invalid or the game is over, it plays a sound and stops

if (optPosition == GAME_OVER)
{

Brain.playSound(powerDown);

return;
}

else if (optPosition == INVALID_POSITION) {

Brain.playSound(wrench);

return;
}

// moves to pickup up the pieces, lowers itself, grabs the piece, and lifts back

// into the air

if (turnXO == 'X')

moveToXY(BOARD_POSITIONS[X_PICKUP][X], BOARD_POSITIONS[X_PICKUP][Y]);

else

moveToXY(BOARD_POSITIONS[O_PICKUP][X], BOARD_POSITIONS[O_PICKUP][Y]);

A19

// ensures at least one piece is left in the stack

// Grabs the piece and lifts it

if (turnXO == 'X')

moveToZ(PICKUP_X_Z[piecesLeft - 1]);

else if (turnXO == 'O')

moveToZ(PICKUP_O_Z[piecesLeft]);

wait(ACTION_WAIT_TIME, seconds);

clawOn();

wait(ACTION_WAIT_TIME, seconds);

// moves to the optimal square and releases the pieces

resetPosition();

moveToXY(BOARD_POSITIONS[optPosition][X], BOARD_POSITIONS[optPosition][Y]);

MotorZ.setStopping(coast);

MotorZ.stop();

MotorZ.setStopping(hold);

wait(ACTION_WAIT_TIME, seconds);

clawOff();

resetPosition();
}

void resetPosition()
{

const int XY_RESET_TIME = 4;

const int Z_RESET_TIME = 3;

// moves the z motor as high as possible

MotorZ.spin(reverse);

wait(Z_RESET_TIME, seconds);

MotorZ.stop();

MotorZ.setPosition(0, degrees);

// moves the x and y motors to the corner

MotorX.spin(forward);

A20

665 | MotorY.spin(forward);
666 | wait(XY_RESET_TIME, seconds);
667 | MotorX.stop();
668 | MotorY.stop();
669 | MotorX.setPosition(0, degrees);
670 | MotorY.setPosition(0, degrees);
671 | }

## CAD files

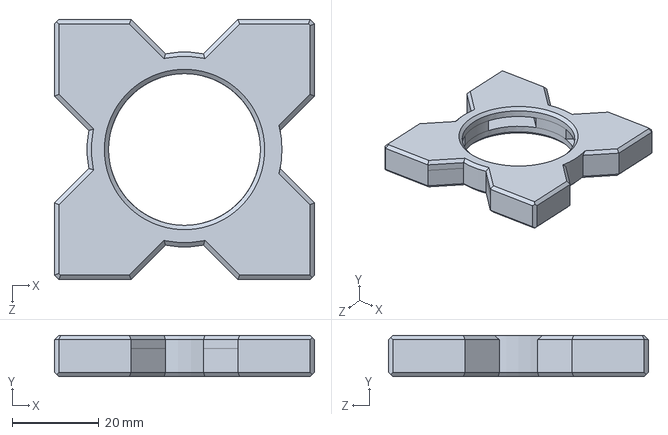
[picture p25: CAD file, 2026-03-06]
CAD/Part_X.SLDPRT
60.0 x 9.50 x 60.0 mm

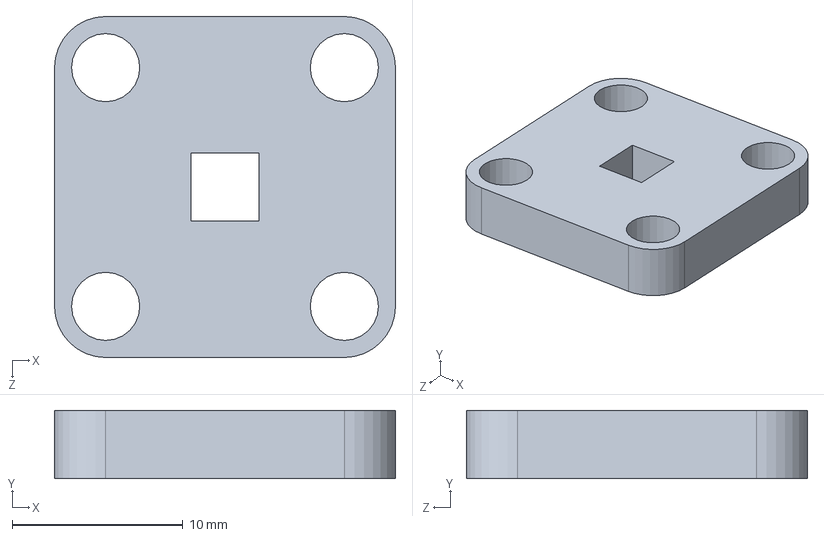
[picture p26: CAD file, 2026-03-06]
CAD/Pointy thing holder.SLDPRT
20.0 x 4.00 x 20.0 mm

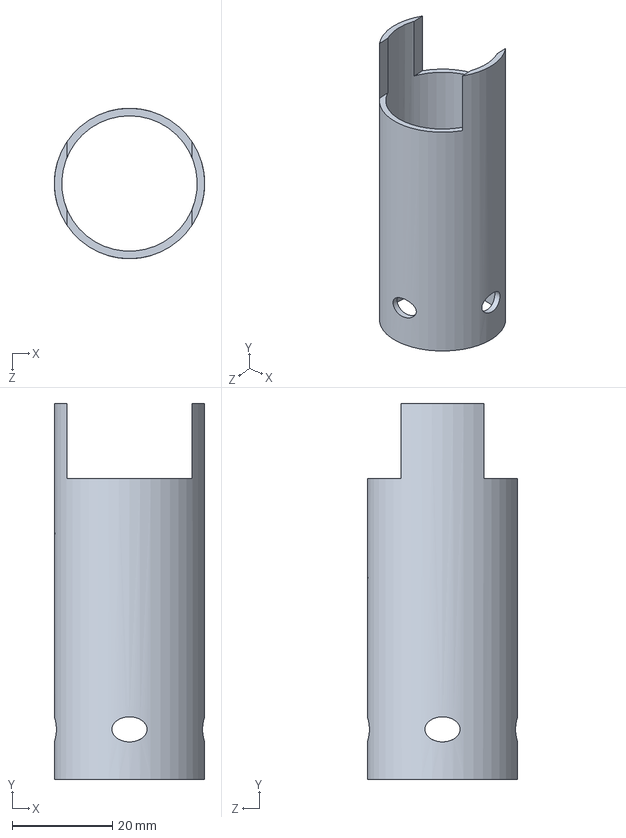
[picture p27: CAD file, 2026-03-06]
CAD/Claw guide.SLDPRT
30.0 x 75.0 x 30.0 mm

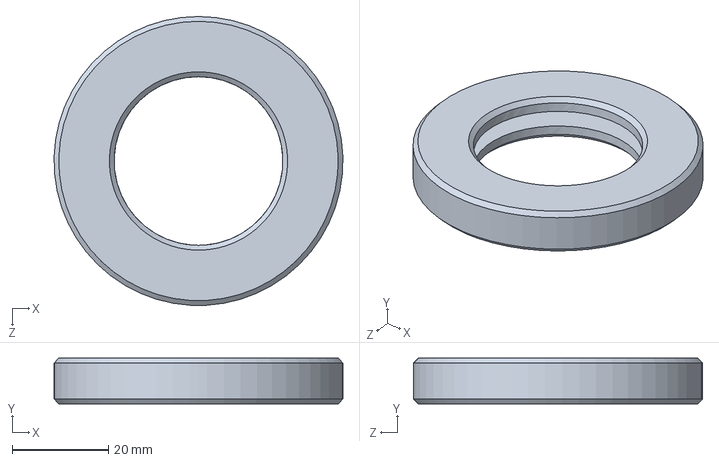
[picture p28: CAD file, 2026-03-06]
CAD/Part_O.SLDPRT
60.0 x 9.50 x 60.0 mm

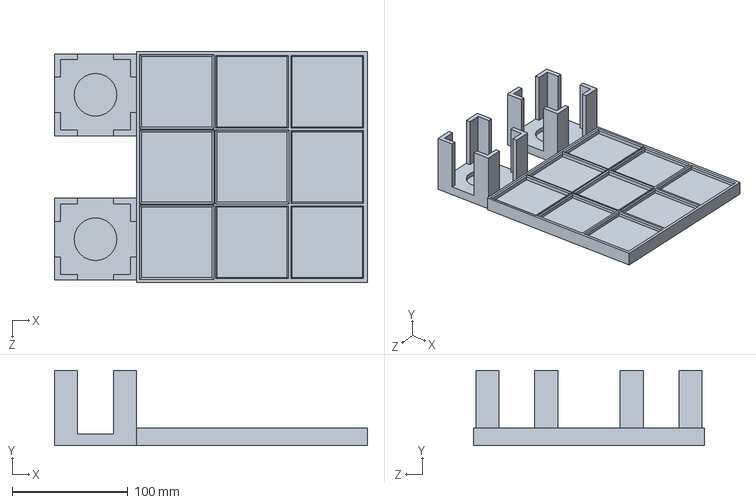
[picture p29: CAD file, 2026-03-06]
CAD/Board.SLDPRT
271.0 x 65.0 x 200.0 mm

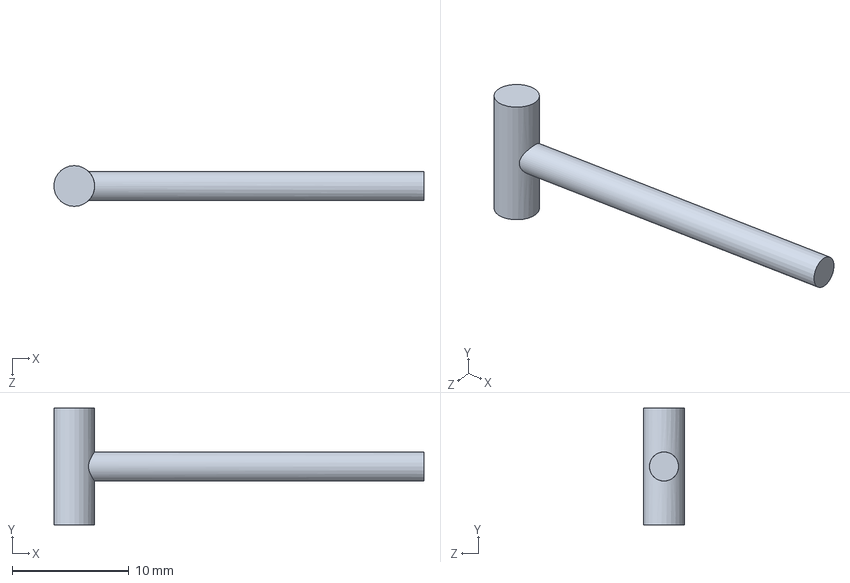
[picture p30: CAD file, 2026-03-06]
CAD/pointy thing.SLDPRT
31.7 x 10.0 x 3.50 mm
